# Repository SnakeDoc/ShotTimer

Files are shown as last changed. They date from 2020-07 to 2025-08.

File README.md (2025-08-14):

Shot Timer
===============================================================================

Copyright 2018 Jason Sipula

A sport shooting training aid that tracks individual shot times, splits and more.

_______________________________________________________________________________

Completed Hardware (LCD Screen disconnected for testing):
PXL_20220328_060556734-EDIT



Circuit Schematic:
schematic

Traces:


Ground and Power Planes:


Bare Board (hand for scale reference):




Board Assembly:




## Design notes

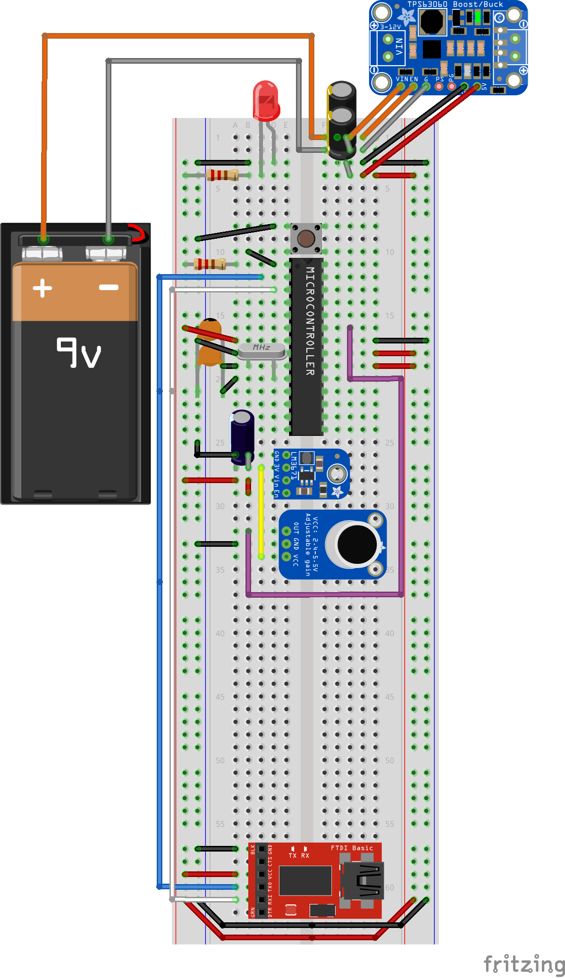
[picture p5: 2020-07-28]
ShotTimer/ShotTimer/hardware/designs/breadboard/Breadboard_Design_bb.png

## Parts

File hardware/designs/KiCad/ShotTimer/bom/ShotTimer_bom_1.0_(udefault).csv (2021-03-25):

Component | Quantity | Reference Designator | Customer Reference | Value | Quantity Per PCB | Digi-Key Part Number | Manufacturer | Manufacturer Part Number | Footprint | Description | Datasheet | Part | References | UserGuide
1 | 1 | BZ1 | BZ1 | Speaker | 1 | 445-2526-1-ND | TDK Corporation | PS1420P02CT | PS1420P02CT | Buzzer, polarized | https://product.tdk.com/info/en/catalog/datasheets/piezoelectronic_buzzer_ps_en.pdf | Buzzer | BZ1
2 | 2 | C15 C16 | C15 C16 | 22pF | 2 | BC1005CT-ND | Vishay Beyschlag/Draloric/BC Components | K220J15C0GF5TL2 | C_Disc_D3.8mm_W2.6mm_P2.50mm | Unpolarized capacitor | https://www.vishay.com/docs/45171/kseries.pdf | C | C15 C16
3 | 1 | C25 | C25 | 100pF | 1 | BC1013CT-ND | Vishay Beyschlag/Draloric/BC Components | K101J15C0GF5TL2 | C_Disc_D3.8mm_W2.6mm_P2.50mm | Unpolarized capacitor | https://www.vishay.com/docs/45171/kseries.pdf | C | C25
4 | 1 | C23 | C23 | 10nF | 1 | 445-173474-1-ND | TDK Corporation | FG28C0G1H103JNT06 | C_Disc_D4.7mm_W2.5mm_P5.00mm | Unpolarized capacitor | https://product.tdk.com/info/en/catalog/datasheets/leadmlcc_halogenfree_fg_en.pdf | C | C23
5 | 10 | C3 C4 C9 C11 C13 C14 C17 C21 C22 C26 | C3 C4 C9 C11 C13 C14 C17 C21 C22 C26 | 0.1uF | 10 | 399-13932-ND | KEMET | C322C104J5R5TA | C_Disc_D5.1mm_W3.2mm_P5.00mm | Unpolarized capacitor | https://content.kemet.com/datasheets/KEM_C1050_GOLDMAX_X7R.pdf | C | C3 C4 C9 C11 C13 C14 C17 C21 C22 C26
6 | 1 | C24 | C24 | 1uF | 1 | 399-13901-ND | KEMET | C330C105J5R5TA | C_Disc_D7.5mm_W4.4mm_P5.00mm | Unpolarized capacitor | https://product.tdk.com/info/en/catalog/datasheets/leadmlcc_halogenfree_fg_en.pdf | C | C24
7 | 9 | C1 C2 C8 C10 C12 C18 C19 C20 C27 | C1 C2 C8 C10 C12 C18 C19 C20 C27 | 10uF | 9 | 445-173370-1-ND | TDK Corporation | FG24X7R1A106KRT06 | C_Disc_D4.7mm_W2.5mm_P5.00mm | Polarized capacitor, US symbol | https://product.tdk.com/info/en/catalog/datasheets/leadmlcc_halogenfree_fg_en.pdf | CP1 | C1 C2 C8 C10 C12 C18 C19 C20 C27
8 | 3 | C5 C6 C7 | C5 C6 C7 | 220uF | 3 | P16296-ND | Panasonic Electronic Components | 16SEPC220MD | CP_Radial_D8.0mm_P3.50mm | Polarized capacitor, US symbol | https://industrial.panasonic.com/cdbs/www-data/pdf/AAB8000/AAB8000C247.pdf | CP1 | C5 C6 C7
9 | 11 | D1 D2 D3 D4 D5 D6 D7 D8 D9 D10 D11 | D1 D2 D3 D4 D5 D6 D7 D8 D9 D10 D11 | 1N5817 | 11 | 497-4547-1-ND | STMicroelectronics | 1N5817 | D_DO-41_SOD81_P10.16mm_Horizontal | 20V 1A Schottky Barrier Rectifier Diode, DO-41 | https://www.st.com/content/ccc/resource/technical/document/datasheet/26/db/14/60/52/47/47/5b/CD00001625.pdf/files/CD00001625.pdf/jcr:content/translations/en.C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 | 1N5817 | D1 D2 D3 D4 D5 D6 D7 D8 D9 D10 D11
10 | 1 | DS1 | DS1 | NHD-0420CW-SPI | 1 | NHD-0420CW-AB3-ND | Newhaven Display Intl | NHD-0420CW-AB3 | NHD_NHD-0420CW-AG3 | 20x4 Character LCD Display Module Passive 5 x 8 Dots OLED Parallel, 8-Bit, I²C, SPI | https://www.newhavendisplay.com/specs/NHD-0420CW-AB3.pdf | NHD-0420CW-SPI | DS1 | https://www.newhavendisplay.com/app_notes/US2066.pdf
11 | 2 | FB1 FB2 | FB1 FB2 | Ferrite_Bead | 2 | 240-2493-ND | Laird-Signal Integrity Products | 28C0236-0JW-10 | LairdTech_28C0236-0JW-10 | Ferrite bead | https://media.digikey.com/pdf/Data%20Sheets/Steward%20PDFs/Part%20Number%20Guide.pdf | Ferrite_Bead | FB1 FB2
12 | 1 | J4 | J4 | Conn_01x20 | 1 | S7053-ND | Sullins Connector Solutions | PPPC201LFBN-RC | PinSocket_1x20_P2.54mm_Vertical | Generic connector, single row, 01x20, script generated (kicad-library-utils/schlib/autogen/connector/) | ~ | Conn_01x20 | J4
13 | 1 | J5 | J5 | Conn_01x20 | 1 | S1211E-20-ND | Sullins Connector Solutions | PBC20SFAN | PinHeader_1x20_P2.54mm_Vertical | Generic connector, single row, 01x20, script generated (kicad-library-utils/schlib/autogen/connector/) | ~ | Conn_01x20 | J5
14 | 1 | J2 | J2 | ISP | 1 | 2057-PH2-06-UA-ND | Adam Tech | PH2-06-UA | PinHeader_2x03_P2.54mm_Vertical | Generic connector, double row, 02x03, odd/even pin numbering scheme (row 1 odd numbers, row 2 even numbers), script generated (kicad-library-utils/schlib/autogen/connector/) | ~ | Conn_02x03_Odd_Even | J2
15 | 1 | J3 | J3 | SERIAL | 1 | 2057-PH1-02-UA-ND | Adam Tech | PH1-02-UA | PinHeader_1x02_P2.54mm_Vertical | Generic connector, single row, 01x02, script generated (kicad-library-utils/schlib/autogen/connector/) | ~ | Conn_01x02 | J3
16 | 1 | J1 | J1 | SYS_PWR | 1 | 732-10955-ND | Würth Elektronik | 691137710002 | TerminalBlock_bornier-2_P5.08mm | Generic screw terminal, single row, 01x02, script generated (kicad-library-utils/schlib/autogen/connector/) | https://www.we-online.de/katalog/datasheet/691137710002.pdf | Screw_Terminal_01x02 | J1
17 | 1 | JP2 | JP2 | ISP_PWR | 1 | 2057-PH1-03-UA-ND | Adam Tech | PH1-03-UA | PinHeader_1x03_P2.54mm_Vertical | Dual jumper, normally closed | ~ | Jumper_NC_Dual | JP2
18 | 1 | JP1 | JP1 | SYS_CFG | 1 | 2057-PH1-02-UA-ND | Adam Tech | PH1-02-UA | PinHeader_1x02_P2.54mm_Vertical | Jumper, 2-pole, open | ~ | Jumper_2_Open | JP1
19 | 1 | L1 | L1 | 33uH | 1 | 308-2103-ND | Sumida America Components Inc. | RCH895NP-330K | L_Radial_D7.8mm_P5.00mm_Fastron_07HCP | Inductor | http://products.sumida.com/products/pdf/RCH-895.pdf | L | L1
20 | 1 | LED1 | LED1 | Green | 1 | 732-5007-ND | Würth Elektronik | 151031VS04000 | LED_D3.0mm | Light emitting diode | https://www.we-online.de/katalog/datasheet/151031VS04000.pdf | LED | LED1
21 | 1 | LED3 | LED3 | Red | 1 | 732-5005-ND | Würth Elektronik | 151031SS04000 | LED_D3.0mm | Light emitting diode | https://katalog.we-online.de/led/datasheet/151031SS04000.pdf | LED | LED3
22 | 2 | LED2 LED4 | LED2 LED4 | Yellow | 2 | 732-5010-ND | Würth Elektronik | 151031YS06000 | LED_D3.0mm | Light emitting diode | https://www.we-online.de/katalog/datasheet/151031YS06000.pdf | LED | LED2 LED4
23 | 1 | MK1 | MK1 | CMA-4544PF-W | 1 | 102-1721-ND | CUI Devices | CMA-4544PF-W | MIC_CMA-4544PF-W |  | https://www.cuidevices.com/product/resource/cma-4544pf-w.pdf | CMA-4544PF-W | MK1
24 | 1 | Q1 | Q1 | Q_NPN_EBC | 1 | KSP2222ABUFS-ND | ON Semiconductor | KSP2222ABU | TO-92 | NPN transistor, emitter/base/collector | https://www.onsemi.com/pub/Collateral/KSP2222A-D.PDF | Q_NPN_EBC | Q1
25 | 1 | Q2 | Q2 | Q_PNP_CBE | 1 | PN2907-ND | ON Semiconductor | PN2907BU | TO-92 | PNP transistor, collector/base/emitter | https://media.digikey.com/pdf/Data%20Sheets/Fairchild%20PDFs/MMBT2907A_PN2907A_PZT2907A.pdf | Q_PNP_CBE | Q2
26 | 4 | R21 R22 R23 R24 | R21 R22 R23 R24 | 330 | 4 | S330CACT-ND | Stackpole Electronics Inc | RNMF14FTC330R | R_Axial_DIN0204_L3.6mm_D1.6mm_P5.08mm_Horizontal | Resistor, US symbol | https://www.seielect.com/catalog/sei-rnf_rnmf.pdf | R_US | R21 R22 R23 R24
27 | 1 | R17 | R17 | 1K | 1 | RNF14FTD1K00CT-ND | Stackpole Electronics Inc | RNF14FTD1K00 | R_Axial_DIN0207_L6.3mm_D2.5mm_P7.62mm_Horizontal | Resistor, US symbol | https://www.seielect.com/catalog/sei-rnf_rnmf.pdf | R_US | R17
28 | 2 | R29 R30 | R29 R30 | 2K | 2 | RNF14FTD2K00CT-ND | Stackpole Electronics Inc | RNF14FTD2K00 | R_Axial_DIN0207_L6.3mm_D2.5mm_P7.62mm_Horizontal | Resistor, US symbol | https://www.seielect.com/catalog/sei-rnf_rnmf.pdf | R_US | R29 R30
29 | 25 | R1 R2 R3 R6 R7 R8 R9 R10 R11 R12 R13 R14 R16 R18 R19 R20 R25 R26 R27 R28 R31 R32 R35 R36 R37 | R1 R2 R3 R6 R7 R8 R9 R10 R11 R12 R13 R14 R16 R18 R19 R20 R25 R26 R27 R28 R31 R32 R35 R36 R37 | 10K | 25 | RNF14FTD10K0CT-ND | Stackpole Electronics Inc | RNF14FTD10K0 | R_Axial_DIN0207_L6.3mm_D2.5mm_P7.62mm_Horizontal | Resistor, US symbol | https://www.seielect.com/catalog/sei-rnf_rnmf.pdf | R_US | R1 R2 R3 R6 R7 R8 R9 R10 R11 R12 R13 R14 R16 R18 R19 R20 R25 R26 R27 R28 R31 R32 R35 R36 R37
30 | 2 | R15 R38 | R15 R38 | 100K | 2 | RNF14FTD100KCT-ND | Stackpole Electronics Inc | RNF14FTD100K | R_Axial_DIN0207_L6.3mm_D2.5mm_P7.62mm_Horizontal | Resistor, US symbol | https://www.seielect.com/catalog/sei-rnf_rnmf.pdf | R_US | R15 R38
31 | 2 | R33 R34 | R33 R34 | 1M | 2 | RNF14FTD1M00CT-ND | Stackpole Electronics Inc | RNF14FTD1M00 | R_Axial_DIN0207_L6.3mm_D2.5mm_P7.62mm_Horizontal | Resistor, US symbol | https://www.seielect.com/catalog/sei-rnf_rnmf.pdf | R_US | R33 R34
32 | 1 | R4 | R4 | 316K 1% | 1 | RNF14FTD316KCT-ND | Stackpole Electronics Inc | RNF14FTD316K | R_Axial_DIN0207_L6.3mm_D2.5mm_P7.62mm_Horizontal | Resistor, US symbol | https://www.seielect.com/catalog/sei-rnf_rnmf.pdf | R_US | R4
33 | 1 | R5 | R5 | 412K 1% | 1 | RNF14FTD412KCT-ND | Stackpole Electronics Inc | RNF14FTD412K | R_Axial_DIN0207_L6.3mm_D2.5mm_P7.62mm_Horizontal | Resistor, US symbol | https://www.seielect.com/catalog/sei-rnf_rnmf.pdf | R_US | R5
34 | 8 | SW1 SW2 SW3 SW4 SW5 SW6 SW7 SW8 | SW1 SW2 SW3 SW4 SW5 SW6 SW7 SW8 | BTN | 8 | SW400-ND | Omron Electronics Inc-EMC Div | B3F-1000 | SW_TH_Tactile_Omron_B3F-10xx | Push button switch, generic, two pins | https://omronfs.omron.com/en_US/ecb/products/pdf/en-b3f.pdf | SW_Push | SW1 SW2 SW3 SW4 SW5 SW6 SW7 SW8
35 | 1 | SW9 | SW9 | Reset | 1 | SW950-ND | Omron Electronics Inc-EMC Div | B3F-1006 | SW_TH_Tactile_Omron_B3F-10xx | Push button switch, generic, two pins | https://omronfs.omron.com/en_US/ecb/products/pdf/en-b3f.pdf | SW_Push | SW9
36 | 1 | U7 | U7 | 25LC1024-I/P | 1 | 25LC1024-I/P-ND | Microchip Technology | 25LC1024-I/P | DIP-8_W7.62mm | SPI Serial EEPROM, DIP-8/SOIC-8/TSSOP-8 | https://ww1.microchip.com/downloads/en/DeviceDoc/22064D.pdf | 25LCxxx | U7
37 | 1 | U5 | U5 | ATmega328P-PU | 1 | ATMEGA328P-PU-ND | Microchip Technology | ATMEGA328P-PU | DIP-28_W7.62mm |  | http://ww1.microchip.com/downloads/en/DeviceDoc/ATmega328_P%20AVR%20MCU%20with%20picoPower%20Technology%20Data%20Sheet%2040001984A.pdf | ATmega328P-PU-UserLibrary | U5
38 | 1 | U4 | U4 | LT1303CN8-5#PBF | 1 | LT1303CN8-5#PBF-ND | Analog Devices Inc. | LT1303CN8-5#PBF | PDIP-8_N |  | https://www.analog.com/media/en/technical-documentation/data-sheets/lt1303.pdf | LT1303CN8-5#PBF-UserLibrary | U4
39 | 1 | U8 | U8 | MAX4466EXK | 1 | MAX4466EXK+CT-ND | Maxim Integrated | MAX4466EXK+T | SOT65P210X110-5N |  | https://datasheets.maximintegrated.com/en/ds/MAX4465-MAX4469.pdf | MAX4466EXK | U8
40 | 1 | U6 | U6 | MCP3201 | 1 | MCP3201-CI/P-ND | Microchip Technology | MCP3201-CI/P | DIP-8_W7.62mm |  | https://ww1.microchip.com/downloads/en/DeviceDoc/21290F.pdf | MCP3201_TriStateMISO-UserLibrary | U6
41 | 1 | U3 | U3 | RN4871-I/RM140 | 1 | 150-RN4871-I/RM140-ND | Microchip Technology | RN4871-I/RM140 | Microchip_RN4871 | Bluetooth Low Energy 4.2 Module | https://ww1.microchip.com/downloads/en/DeviceDoc/RN4870-71-Data-Sheet-DS50002489E.pdf | RN4871 | U3 | https://ww1.microchip.com/downloads/en/DeviceDoc/RN4870-71-Bluetooth-Low-Energy-Module-User-Guide-DS50002466C.pdf
42 | 1 | U1 | U1 | SN74HC153N | 1 | 296-8238-5-ND | Texas Instruments | SN74HC153N | DIP794W45P254L1969H508Q16 |  | https://www.ti.com/lit/ds/symlink/sn74hc153.pdf | SN74HC153N | U1
43 | 1 | U2 | U2 | TSR_1-2433 | 1 | 1951-2742-ND | Traco Power | TSR 1-2433 | Converter_DCDC_TRACO_TSR-1_THT | 1A step-down regulator module, fixed 3.3V output voltage, 5-36V input voltage, -40°C to +85°C temperature range, TO-220 compatible LM78xx replacement | https://www.tracopower.com/sites/default/files/products/datasheets/tsr1_datasheet.pdf | TSR_1-2433 | U2
44 | 1 | Y1 | Y1 | 16MHz | 1 | 887-1244-ND | TXC CORPORATION | 9B-16.000MEEJ-B | Crystal_HC49-U_Vertical | Two pin crystal | http://www.txccrystal.com/images/pdf/9b-accuracy.pdf | Crystal | Y1
Component Groups: | 44
Component Count: | 113
Fitted Components: | 113
Number of PCBs: | 1
Total components: | 113
Schematic Version: | 1.0
Schematic Date: | 2021-02-14
PCB Variant: | udefault
BoM Date: | 2/17/2021 12:20:09 AM
Schematic Source: | ShotTimer.sch
KiCad Version: | Eeschema (5.1.9)-1

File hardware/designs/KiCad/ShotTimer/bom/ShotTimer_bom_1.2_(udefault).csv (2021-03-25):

Component | Quantity | Reference Designator | Customer Reference | Value | Quantity Per PCB | Digi-Key Part Number | Manufacturer | Manufacturer Part Number | Footprint | Description | Datasheet | Part | Mouser Part Number | Build Quantity | References | UserGuide
1 | 3 | BZ1 | BZ1 | Speaker | 1 | 445-2526-1-ND | TDK Corporation | PS1420P02CT | PS1420P02CT | Buzzer, polarized | https://product.tdk.com/info/en/catalog/datasheets/piezoelectronic_buzzer_ps_en.pdf | Buzzer | 810-PS1420P02CT | 3 | BZ1
2 | 6 | C15 C16 | C15 C16 | 22pF | 2 | BC1005CT-ND | Vishay Beyschlag/Draloric/BC Components | K220J15C0GF5TL2 | C_Disc_D3.8mm_W2.6mm_P2.50mm | Unpolarized capacitor | https://www.vishay.com/docs/45171/kseries.pdf | C | 594-K220J15C0GF5TL2 | 6 | C15 C16
3 | 3 | C25 | C25 | 100pF | 1 | BC1013CT-ND | Vishay Beyschlag/Draloric/BC Components | K101J15C0GF5TL2 | C_Disc_D3.8mm_W2.6mm_P2.50mm | Unpolarized capacitor | https://www.vishay.com/docs/45171/kseries.pdf | C | 594-K101J15C0GF5TL2 | 3 | C25
4 | 3 | C23 | C23 | 10nF | 1 | 445-173474-1-ND | TDK Corporation | FG28C0G1H103JNT06 | C_Disc_D4.7mm_W2.5mm_P5.00mm | Unpolarized capacitor | https://product.tdk.com/info/en/catalog/datasheets/leadmlcc_halogenfree_fg_en.pdf | C | 810-FG28C0G1H103JNT6 | 3 | C23
5 | 33 | C1 C2 C3 C4 C9 C13 C14 C17 C21 C22 C26 | C1 C2 C3 C4 C9 C13 C14 C17 C21 C22 C26 | 0.1uF | 11 | 399-13932-ND | KEMET | C322C104J5R5TA | C_Disc_D5.1mm_W3.2mm_P5.00mm | Unpolarized capacitor | https://content.kemet.com/datasheets/KEM_C1050_GOLDMAX_X7R.pdf | C | 80-C322C104J5R | 33 | C1 C2 C3 C4 C9 C13 C14 C17 C21 C22 C26
6 | 3 | C24 | C24 | 1uF | 1 | 399-13901-ND | KEMET | C330C105J5R5TA | C_Disc_D7.5mm_W4.4mm_P5.00mm | Unpolarized capacitor | https://product.tdk.com/info/en/catalog/datasheets/leadmlcc_halogenfree_fg_en.pdf | C | 80-C330C105J5R | 3 | C24
7 | 9 | C5 C6 C7 | C5 C6 C7 | 220uF | 3 | P16296-ND | Panasonic Electronic Components | 16SEPC220MD | CP_Radial_D8.0mm_P3.50mm | Polarized capacitor, US symbol | https://industrial.panasonic.com/cdbs/www-data/pdf/AAB8000/AAB8000C247.pdf | CP1 | 667-16SEPC220MD | 9 | C5 C6 C7
8 | 33 | D1 D2 D3 D4 D5 D6 D7 D8 D9 D10 D11 | D1 D2 D3 D4 D5 D6 D7 D8 D9 D10 D11 | 1N5817 | 11 | 497-4547-1-ND | STMicroelectronics | 1N5817 | D_DO-41_SOD81_P10.16mm_Horizontal | 20V 1A Schottky Barrier Rectifier Diode, DO-41 | https://www.st.com/content/ccc/resource/technical/document/datasheet/26/db/14/60/52/47/47/5b/CD00001625.pdf/files/CD00001625.pdf/jcr:content/translations/en.C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 | 1N5817 | 511-1N5817 | 33 | D1 D2 D3 D4 D5 D6 D7 D8 D9 D10 D11
9 | 3 | DS1 | DS1 | NHD-0420CW-SPI | 1 | NHD-0420CW-AB3-ND | Newhaven Display Intl | NHD-0420CW-AB3 | NHD_NHD-0420CW-AG3 | 20x4 Character LCD Display Module Passive 5 x 8 Dots OLED Parallel, 8-Bit, I²C, SPI | https://www.newhavendisplay.com/specs/NHD-0420CW-AB3.pdf | NHD-0420CW-SPI | 763-NHD-0420CW-AB3 | 3 | DS1 | https://www.newhavendisplay.com/app_notes/US2066.pdf
10 | 6 | FB1 FB2 | FB1 FB2 | Ferrite_Bead | 2 | 240-2493-ND | Laird-Signal Integrity Products | 28C0236-0JW-10 | LairdTech_28C0236-0JW-10 | Ferrite bead | https://media.digikey.com/pdf/Data%20Sheets/Steward%20PDFs/Part%20Number%20Guide.pdf | Ferrite_Bead | 875-28C0236-0JW-10 | 6 | FB1 FB2
11 | 3 | J2 | J2 | ISP | 1 | 2057-PH2-06-UA-ND | Adam Tech | PH2-06-UA | PinHeader_2x03_P2.54mm_Vertical | Generic connector, double row, 02x03, odd/even pin numbering scheme (row 1 odd numbers, row 2 even numbers), script generated (kicad-library-utils/schlib/autogen/connector/) | ~ | Conn_02x03_Odd_Even |  | 3 | J2
12 | 3 | J3 | J3 | SERIAL | 1 | 2057-PH1-02-UA-ND | Adam Tech | PH1-02-UA | PinHeader_1x02_P2.54mm_Vertical | Generic connector, single row, 01x02, script generated (kicad-library-utils/schlib/autogen/connector/) | ~ | Conn_01x02 |  | 3 | J3
13 | 3 | J1 | J1 | SYS_PWR | 1 | 732-10955-ND | Würth Elektronik | 691137710002 | TerminalBlock_bornier-2_P5.08mm | Generic screw terminal, single row, 01x02, script generated (kicad-library-utils/schlib/autogen/connector/) | https://www.we-online.de/katalog/datasheet/691137710002.pdf | Screw_Terminal_01x02 | 710-691137710002 | 3 | J1
14 | 3 | JP2 | JP2 | ISP_PWR | 1 | 2057-PH1-03-UA-ND | Adam Tech | PH1-03-UA | PinHeader_1x03_P2.54mm_Vertical | Dual jumper, normally closed | ~ | Jumper_NC_Dual |  | 3 | JP2
15 | 3 | JP1 | JP1 | SYS_CFG | 1 | 2057-PH1-02-UA-ND | Adam Tech | PH1-02-UA | PinHeader_1x02_P2.54mm_Vertical | Jumper, 2-pole, open | ~ | Jumper_2_Open |  | 3 | JP1
16 | 3 | L1 | L1 | 33uH | 1 | 308-2103-ND | Sumida America Components Inc. | RCH895NP-330K | L_Radial_D7.8mm_P5.00mm_Fastron_07HCP | Inductor | http://products.sumida.com/products/pdf/RCH-895.pdf | L | 851-RCH895NP-330K | 3 | L1
17 | 3 | LED1 | LED1 | Green | 1 | 732-5007-ND | Würth Elektronik | 151031VS04000 | LED_D3.0mm | Light emitting diode | https://www.we-online.de/katalog/datasheet/151031VS04000.pdf | LED | 710-151031VS04000 | 3 | LED1
18 | 3 | LED3 | LED3 | Red | 1 | 732-5005-ND | Würth Elektronik | 151031SS04000 | LED_D3.0mm | Light emitting diode | https://katalog.we-online.de/led/datasheet/151031SS04000.pdf | LED | 710-151031SS04000 | 3 | LED3
19 | 6 | LED2 LED4 | LED2 LED4 | Yellow | 2 | 732-5010-ND | Würth Elektronik | 151031YS06000 | LED_D3.0mm | Light emitting diode | https://www.we-online.de/katalog/datasheet/151031YS06000.pdf | LED | 710-151031YS06000 | 6 | LED2 LED4
20 | 3 | MK1 | MK1 | CMA-4544PF-W | 1 | 102-1721-ND | CUI Devices | CMA-4544PF-W | MIC_CMA-4544PF-W |  | https://www.cuidevices.com/product/resource/cma-4544pf-w.pdf | CMA-4544PF-W | 490-CMA-4544PF-W | 3 | MK1
21 | 3 | Q1 | Q1 | Q_NPN_EBC | 1 | KSP2222ABUFS-ND | ON Semiconductor | KSP2222ABU | TO-92 | NPN transistor, emitter/base/collector | https://www.onsemi.com/pub/Collateral/KSP2222A-D.PDF | Q_NPN_EBC | 512-KSP2222ABU | 3 | Q1
22 | 3 | Q2 | Q2 | Q_PNP_CBE | 1 | PN2907-ND | ON Semiconductor | PN2907BU | TO-92 | PNP transistor, collector/base/emitter | https://media.digikey.com/pdf/Data%20Sheets/Fairchild%20PDFs/MMBT2907A_PN2907A_PZT2907A.pdf | Q_PNP_CBE | 512-PN2907BU | 3 | Q2
23 | 12 | R21 R22 R23 R24 | R21 R22 R23 R24 | 330 | 4 | S330CACT-ND | Stackpole Electronics Inc | RNMF14FTC330R | R_Axial_DIN0204_L3.6mm_D1.6mm_P5.08mm_Horizontal | Resistor, US symbol | https://www.seielect.com/catalog/sei-rnf_rnmf.pdf | R_US |  | 12 | R21 R22 R23 R24
24 | 3 | R17 | R17 | 1K | 1 | RNF14FTD1K00CT-ND | Stackpole Electronics Inc | RNF14FTD1K00 | R_Axial_DIN0207_L6.3mm_D2.5mm_P7.62mm_Horizontal | Resistor, US symbol | https://www.seielect.com/catalog/sei-rnf_rnmf.pdf | R_US |  | 3 | R17
25 | 6 | R29 R30 | R29 R30 | 2K | 2 | RNF14FTD2K00CT-ND | Stackpole Electronics Inc | RNF14FTD2K00 | R_Axial_DIN0207_L6.3mm_D2.5mm_P7.62mm_Horizontal | Resistor, US symbol | https://www.seielect.com/catalog/sei-rnf_rnmf.pdf | R_US |  | 6 | R29 R30
26 | 78 | R1 R2 R3 R6 R7 R8 R9 R10 R11 R12 R13 R14 R16 R18 R19 R20 R25 R26 R27 R28 R31 R32 R35 R36 R37 R39 | R1 R2 R3 R6 R7 R8 R9 R10 R11 R12 R13 R14 R16 R18 R19 R20 R25 R26 R27 R28 R31 R32 R35 R36 R37 R39 | 10K | 26 | RNF14FTD10K0CT-ND | Stackpole Electronics Inc | RNF14FTD10K0 | R_Axial_DIN0207_L6.3mm_D2.5mm_P7.62mm_Horizontal | Resistor, US symbol | https://www.seielect.com/catalog/sei-rnf_rnmf.pdf | R_US |  | 78 | R1 R2 R3 R6 R7 R8 R9 R10 R11 R12 R13 R14 R16 R18 R19 R20 R25 R26 R27 R28 R31 R32 R35 R36 R37 R39
27 | 6 | R15 R38 | R15 R38 | 100K | 2 | RNF14FTD100KCT-ND | Stackpole Electronics Inc | RNF14FTD100K | R_Axial_DIN0207_L6.3mm_D2.5mm_P7.62mm_Horizontal | Resistor, US symbol | https://www.seielect.com/catalog/sei-rnf_rnmf.pdf | R_US |  | 6 | R15 R38
28 | 6 | R33 R34 | R33 R34 | 1M | 2 | RNF14FTD1M00CT-ND | Stackpole Electronics Inc | RNF14FTD1M00 | R_Axial_DIN0207_L6.3mm_D2.5mm_P7.62mm_Horizontal | Resistor, US symbol | https://www.seielect.com/catalog/sei-rnf_rnmf.pdf | R_US |  | 6 | R33 R34
29 | 3 | R4 | R4 | 316K 1% | 1 | RNF14FTD316KCT-ND | Stackpole Electronics Inc | RNF14FTD316K | R_Axial_DIN0207_L6.3mm_D2.5mm_P7.62mm_Horizontal | Resistor, US symbol | https://www.seielect.com/catalog/sei-rnf_rnmf.pdf | R_US |  | 3 | R4
30 | 3 | R5 | R5 | 412K 1% | 1 | RNF14FTD412KCT-ND | Stackpole Electronics Inc | RNF14FTD412K | R_Axial_DIN0207_L6.3mm_D2.5mm_P7.62mm_Horizontal | Resistor, US symbol | https://www.seielect.com/catalog/sei-rnf_rnmf.pdf | R_US |  | 3 | R5
31 | 24 | SW1 SW2 SW3 SW4 SW5 SW6 SW7 SW8 | SW1 SW2 SW3 SW4 SW5 SW6 SW7 SW8 | BTN | 8 | SW400-ND | Omron Electronics Inc-EMC Div | B3F-1000 | SW_B3F-10xx | Push button switch, generic, two pins | https://omronfs.omron.com/en_US/ecb/products/pdf/en-b3f.pdf | SW_Push_2-4 | 653-B3F-1000 | 24 | SW1 SW2 SW3 SW4 SW5 SW6 SW7 SW8
32 | 3 | SW9 | SW9 | Reset | 1 | SW950-ND | Omron Electronics Inc-EMC Div | B3F-1006 | SW_B3F-10xx | Push button switch, generic, two pins | https://omronfs.omron.com/en_US/ecb/products/pdf/en-b3f.pdf | SW_Push_1-3 | 653-B3F-1006 | 3 | SW9
33 | 3 | U7 | U7 | 25LC1024-I/P | 1 | 25LC1024-I/P-ND | Microchip Technology | 25LC1024-I/P | DIP-8_W7.62mm | SPI Serial EEPROM, DIP-8/SOIC-8/TSSOP-8 | https://ww1.microchip.com/downloads/en/DeviceDoc/22064D.pdf | 25LCxxx | 579-25LC1024-I/P | 3 | U7
34 | 3 | U5 | U5 | ATmega328P-PU | 1 | ATMEGA328P-PU-ND | Microchip Technology | ATMEGA328P-PU | DIP-28_W7.62mm |  | http://ww1.microchip.com/downloads/en/DeviceDoc/ATmega328_P%20AVR%20MCU%20with%20picoPower%20Technology%20Data%20Sheet%2040001984A.pdf | ATmega328P-PU-UserLibrary | 556-ATMEGA328P-PU | 3 | U5
35 | 3 | U1 | U1 | CD74HC151E | 1 | 296-25973-5-ND | Texas Instruments | CD74HC151E | DIP-16_W7.62mm |  | https://www.ti.com/lit/ds/symlink/cd74hc151.pdf | CD74HC151E-EZLayout | 595-CD74HC151E | 3 | U1
36 | 3 | U4 | U4 | LT1303CN8-5#PBF | 1 | LT1303CN8-5#PBF-ND | Analog Devices Inc. | LT1303CN8-5#PBF | PDIP-8_N |  | https://www.analog.com/media/en/technical-documentation/data-sheets/lt1303.pdf | LT1303CN8-5#PBF-UserLibrary | 584-LT1303CN8-5#PBF | 3 | U4
37 | 3 | U8 | U8 | MAX4466EXK | 1 | MAX4466EXK+CT-ND | Maxim Integrated | MAX4466EXK+T | SOT65P210X110-5N |  | https://datasheets.maximintegrated.com/en/ds/MAX4465-MAX4469.pdf | MAX4466EXK | 700-MAX4466EXKT | 3 | U8
38 | 3 | U6 | U6 | MCP3201 | 1 | MCP3201-CI/P-ND | Microchip Technology | MCP3201-CI/P | DIP-8_W7.62mm |  | https://ww1.microchip.com/downloads/en/DeviceDoc/21290F.pdf | MCP3201_TriStateMISO-UserLibrary | 579-MCP3201-CI/P | 3 | U6
39 | 3 | U3 | U3 | RN4871-I/RM140 | 1 | 150-RN4871-I/RM140-ND | Microchip Technology | RN4871-I/RM140 | Microchip_RN4871 | Bluetooth Low Energy 4.2 Module | https://ww1.microchip.com/downloads/en/DeviceDoc/RN4870-71-Data-Sheet-DS50002489E.pdf | RN4871 | 579-RN4871-I/RM140 | 3 | U3 | https://ww1.microchip.com/downloads/en/DeviceDoc/RN4870-71-Bluetooth-Low-Energy-Module-User-Guide-DS50002466C.pdf
40 | 3 | U2 | U2 | TSR_1-2433 | 1 | 1951-2742-ND | Traco Power | TSR 1-2433 | Converter_DCDC_TRACO_TSR-1_THT | 1A step-down regulator module, fixed 3.3V output voltage, 5-36V input voltage, -40°C to +85°C temperature range, TO-220 compatible LM78xx replacement | https://www.tracopower.com/sites/default/files/products/datasheets/tsr1_datasheet.pdf | TSR_1-2433 | 495-TSR-1-2433 | 3 | U2
41 | 3 | Y1 | Y1 | 16MHz | 1 | 887-1244-ND | TXC CORPORATION | 9B-16.000MEEJ-B | Crystal_HC49-U_Vertical | Two pin crystal | http://www.txccrystal.com/images/pdf/9b-accuracy.pdf | Crystal | 717-9B-16.000MEEJ-B | 3 | Y1
Component Groups: | 41
Component Count: | 104
Fitted Components: | 104
Number of PCBs: | 3
Total components: | 312
Schematic Version: | 1.2
Schematic Date: | 2021-03-06
PCB Variant: | udefault
BoM Date: | 3/8/2021 11:59:04 PM
Schematic Source: | ShotTimer.sch
KiCad Version: | Eeschema (5.1.9)-1

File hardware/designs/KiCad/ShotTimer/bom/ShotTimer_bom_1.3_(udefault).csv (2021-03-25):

Component | Quantity | Reference Designator | Customer Reference | Value | Quantity Per PCB | Digi-Key Part Number | Manufacturer | Manufacturer Part Number | Footprint | Description | Datasheet | Part | Build Quantity | References | Mouser Part Number | UserGuide
1 | 4 | BOM1 BOM2 | BOM1 BOM2 | Jumper | 2 | S9337-ND | Sullins Connector Solutions | QPC02SXGN-RC |  |  | https://s3.amazonaws.com/catalogspreads-pdf/PAGE128-129%20.100%20JUMPER.pdf | BOM_ITEM-UserLibrary | 4 | BOM1 BOM2
2 | 4 | BOM3 BOM4 | BOM3 BOM4 | Support | 2 | RPC1348-ND | Essentra Components | MDLSP1-09M-01 |  |  | https://www.essentracomponents.com.sg/images-line/pdfs/MDLSP1-09M-01.pdf | BOM_ITEM-UserLibrary | 4 | BOM3 BOM4
3 | 2 | BZ1 | BZ1 | Speaker | 1 | 445-2526-1-ND | TDK Corporation | PS1420P02CT | PS1420P02CT | Buzzer, polarized | https://product.tdk.com/info/en/catalog/datasheets/piezoelectronic_buzzer_ps_en.pdf | Buzzer | 2 | BZ1 | 810-PS1420P02CT
4 | 4 | C15 C16 | C15 C16 | 22pF | 2 | BC1005CT-ND | Vishay Beyschlag/Draloric/BC Components | K220J15C0GF5TL2 | C_Disc_D3.8mm_W2.6mm_P2.50mm | Unpolarized capacitor | https://www.vishay.com/docs/45171/kseries.pdf | C | 4 | C15 C16 | 594-K220J15C0GF5TL2
5 | 2 | C25 | C25 | 100pF | 1 | BC1013CT-ND | Vishay Beyschlag/Draloric/BC Components | K101J15C0GF5TL2 | C_Disc_D3.8mm_W2.6mm_P2.50mm | Unpolarized capacitor | https://www.vishay.com/docs/45171/kseries.pdf | C | 2 | C25 | 594-K101J15C0GF5TL2
6 | 2 | C23 | C23 | 10nF | 1 | 445-173474-1-ND | TDK Corporation | FG28C0G1H103JNT06 | C_Disc_D4.7mm_W2.5mm_P5.00mm | Unpolarized capacitor | https://product.tdk.com/info/en/catalog/datasheets/leadmlcc_halogenfree_fg_en.pdf | C | 2 | C23 | 810-FG28C0G1H103JNT6
7 | 22 | C1 C2 C3 C4 C9 C13 C14 C17 C21 C22 C26 | C1 C2 C3 C4 C9 C13 C14 C17 C21 C22 C26 | 0.1uF | 11 | 399-13932-ND | KEMET | C322C104J5R5TA | C_Disc_D5.1mm_W3.2mm_P5.00mm | Unpolarized capacitor | https://content.kemet.com/datasheets/KEM_C1050_GOLDMAX_X7R.pdf | C | 22 | C1 C2 C3 C4 C9 C13 C14 C17 C21 C22 C26 | 80-C322C104J5R
8 | 2 | C24 | C24 | 1uF | 1 | 399-13901-ND | KEMET | C330C105J5R5TA | C_Disc_D7.5mm_W4.4mm_P5.00mm | Unpolarized capacitor | https://product.tdk.com/info/en/catalog/datasheets/leadmlcc_halogenfree_fg_en.pdf | C | 2 | C24 | 80-C330C105J5R
9 | 6 | C5 C6 C7 | C5 C6 C7 | 220uF | 3 | P16296-ND | Panasonic Electronic Components | 16SEPC220MD | CP_Radial_D8.0mm_P3.50mm | Polarized capacitor, US symbol | https://industrial.panasonic.com/cdbs/www-data/pdf/AAB8000/AAB8000C247.pdf | CP1 | 6 | C5 C6 C7 | 667-16SEPC220MD
10 | 22 | D1 D2 D3 D4 D5 D6 D7 D8 D9 D10 D11 | D1 D2 D3 D4 D5 D6 D7 D8 D9 D10 D11 | 1N5817 | 11 | 497-4547-1-ND | STMicroelectronics | 1N5817 | D_DO-41_SOD81_P10.16mm_Horizontal | 20V 1A Schottky Barrier Rectifier Diode, DO-41 | https://www.st.com/content/ccc/resource/technical/document/datasheet/26/db/14/60/52/47/47/5b/CD00001625.pdf/files/CD00001625.pdf/jcr:content/translations/en.C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 | 1N5817 | 22 | D1 D2 D3 D4 D5 D6 D7 D8 D9 D10 D11 | 511-1N5817
11 | 2 | DS1 | DS1 | NHD-0420CW-SPI | 1 | NHD-0420CW-AB3-ND | Newhaven Display Intl | NHD-0420CW-AB3 | NHD_NHD-0420CW-AG3 | 20x4 Character LCD Display Module Passive 5 x 8 Dots OLED Parallel, 8-Bit, I²C, SPI | https://www.newhavendisplay.com/specs/NHD-0420CW-AB3.pdf | NHD-0420CW-SPI | 2 | DS1 | 763-NHD-0420CW-AB3 | https://www.newhavendisplay.com/app_notes/US2066.pdf
12 | 4 | FB1 FB2 | FB1 FB2 | Ferrite_Bead | 2 | 240-2493-ND | Laird-Signal Integrity Products | 28C0236-0JW-10 | LairdTech_28C0236-0JW-10 | Ferrite bead | https://media.digikey.com/pdf/Data%20Sheets/Steward%20PDFs/Part%20Number%20Guide.pdf | Ferrite_Bead | 4 | FB1 FB2 | 875-28C0236-0JW-10
13 | 2 | J5 | J5 | Header Conn_01x20 | 1 | S1211E-20-ND | Sullins Connector Solutions | PBC20SFAN | PinHeader_1x20_P2.54mm_Vertical |  | ~ | BOM_ITEM-UserLibrary | 2 | J5
14 | 2 | J2 | J2 | ISP | 1 | 2057-PH2-06-UA-ND | Adam Tech | PH2-06-UA | PinHeader_2x03_P2.54mm_Vertical | Generic connector, double row, 02x03, odd/even pin numbering scheme (row 1 odd numbers, row 2 even numbers), script generated (kicad-library-utils/schlib/autogen/connector/) | ~ | Conn_02x03_Odd_Even | 2 | J2
15 | 2 | J3 | J3 | SERIAL | 1 | 2057-PH1-02-UA-ND | Adam Tech | PH1-02-UA | PinHeader_1x02_P2.54mm_Vertical | Generic connector, single row, 01x02, script generated (kicad-library-utils/schlib/autogen/connector/) | ~ | Conn_01x02 | 2 | J3
16 | 2 | J1 | J1 | SYS_PWR | 1 | 732-10955-ND | Würth Elektronik | 691137710002 | TerminalBlock_bornier-2_P5.08mm | Generic screw terminal, single row, 01x02, script generated (kicad-library-utils/schlib/autogen/connector/) | https://www.we-online.de/katalog/datasheet/691137710002.pdf | Screw_Terminal_01x02 | 2 | J1 | 710-691137710002
17 | 2 | J4 | J4 | Socket Conn_01x20 | 1 | S7053-ND | Sullins Connector Solutions | PPPC201LFBN-RC | PinSocket_1x20_P2.54mm_Vertical |  | ~ | BOM_ITEM-UserLibrary | 2 | J4
18 | 2 | JP2 | JP2 | ISP_PWR | 1 | 2057-PH1-03-UA-ND | Adam Tech | PH1-03-UA | PinHeader_1x03_P2.54mm_Vertical | Dual jumper, normally closed | ~ | Jumper_NC_Dual | 2 | JP2
19 | 2 | JP1 | JP1 | SYS_CFG | 1 | 2057-PH1-02-UA-ND | Adam Tech | PH1-02-UA | PinHeader_1x02_P2.54mm_Vertical | Jumper, 2-pole, open | ~ | Jumper_2_Open | 2 | JP1
20 | 2 | L1 | L1 | 33uH | 1 | 308-2103-ND | Sumida America Components Inc. | RCH895NP-330K | L_Radial_D7.8mm_P5.00mm_Fastron_07HCP | Inductor | http://products.sumida.com/products/pdf/RCH-895.pdf | L | 2 | L1 | 851-RCH895NP-330K
21 | 2 | LED1 | LED1 | Green | 1 | 732-5007-ND | Würth Elektronik | 151031VS04000 | LED_D3.0mm | Light emitting diode | https://www.we-online.de/katalog/datasheet/151031VS04000.pdf | LED | 2 | LED1 | 710-151031VS04000
22 | 2 | LED3 | LED3 | Red | 1 | 732-5005-ND | Würth Elektronik | 151031SS04000 | LED_D3.0mm | Light emitting diode | https://katalog.we-online.de/led/datasheet/151031SS04000.pdf | LED | 2 | LED3 | 710-151031SS04000
23 | 4 | LED2 LED4 | LED2 LED4 | Yellow | 2 | 732-5010-ND | Würth Elektronik | 151031YS06000 | LED_D3.0mm | Light emitting diode | https://www.we-online.de/katalog/datasheet/151031YS06000.pdf | LED | 4 | LED2 LED4 | 710-151031YS06000
24 | 2 | MK1 | MK1 | CMA-4544PF-W | 1 | 102-1721-ND | CUI Devices | CMA-4544PF-W | MIC_CMA-4544PF-W |  | https://www.cuidevices.com/product/resource/cma-4544pf-w.pdf | CMA-4544PF-W | 2 | MK1 | 490-CMA-4544PF-W
25 | 2 | Q1 | Q1 | Q_NPN_EBC | 1 | SS8050DBU-ND | ON Semiconductor | SS8050DBU | TO-92 | NPN transistor, emitter/base/collector | https://www.onsemi.com/pdf/datasheet/ss8050-d.pdf | Q_NPN_EBC | 2 | Q1 | 512-SS8050DBU
26 | 2 | Q2 | Q2 | Q_PNP_CBE | 1 | PN2907-ND | ON Semiconductor | PN2907BU | TO-92 | PNP transistor, collector/base/emitter | https://media.digikey.com/pdf/Data%20Sheets/Fairchild%20PDFs/MMBT2907A_PN2907A_PZT2907A.pdf | Q_PNP_CBE | 2 | Q2 | 512-PN2907BU
27 | 8 | R21 R22 R23 R24 | R21 R22 R23 R24 | 330 | 4 | S330CACT-ND | Stackpole Electronics Inc | RNMF14FTC330R | R_Axial_DIN0204_L3.6mm_D1.6mm_P5.08mm_Horizontal | Resistor, US symbol | https://www.seielect.com/catalog/sei-rnf_rnmf.pdf | R_US | 8 | R21 R22 R23 R24
28 | 2 | R17 | R17 | 1K | 1 | RNF14FTD1K00CT-ND | Stackpole Electronics Inc | RNF14FTD1K00 | R_Axial_DIN0207_L6.3mm_D2.5mm_P7.62mm_Horizontal | Resistor, US symbol | https://www.seielect.com/catalog/sei-rnf_rnmf.pdf | R_US | 2 | R17
29 | 4 | R29 R30 | R29 R30 | 2K | 2 | RNF14FTD2K00CT-ND | Stackpole Electronics Inc | RNF14FTD2K00 | R_Axial_DIN0207_L6.3mm_D2.5mm_P7.62mm_Horizontal | Resistor, US symbol | https://www.seielect.com/catalog/sei-rnf_rnmf.pdf | R_US | 4 | R29 R30
30 | 52 | R1 R2 R3 R6 R7 R8 R9 R10 R11 R12 R13 R14 R16 R18 R19 R20 R25 R26 R27 R28 R31 R32 R35 R36 R37 R39 | R1 R2 R3 R6 R7 R8 R9 R10 R11 R12 R13 R14 R16 R18 R19 R20 R25 R26 R27 R28 R31 R32 R35 R36 R37 R39 | 10K | 26 | RNF14FTD10K0CT-ND | Stackpole Electronics Inc | RNF14FTD10K0 | R_Axial_DIN0207_L6.3mm_D2.5mm_P7.62mm_Horizontal | Resistor, US symbol | https://www.seielect.com/catalog/sei-rnf_rnmf.pdf | R_US | 52 | R1 R2 R3 R6 R7 R8 R9 R10 R11 R12 R13 R14 R16 R18 R19 R20 R25 R26 R27 R28 R31 R32 R35 R36 R37 R39
31 | 4 | R15 R38 | R15 R38 | 100K | 2 | RNF14FTD100KCT-ND | Stackpole Electronics Inc | RNF14FTD100K | R_Axial_DIN0207_L6.3mm_D2.5mm_P7.62mm_Horizontal | Resistor, US symbol | https://www.seielect.com/catalog/sei-rnf_rnmf.pdf | R_US | 4 | R15 R38
32 | 4 | R33 R34 | R33 R34 | 1M | 2 | RNF14FTD1M00CT-ND | Stackpole Electronics Inc | RNF14FTD1M00 | R_Axial_DIN0207_L6.3mm_D2.5mm_P7.62mm_Horizontal | Resistor, US symbol | https://www.seielect.com/catalog/sei-rnf_rnmf.pdf | R_US | 4 | R33 R34
33 | 2 | R4 | R4 | 316K 1% | 1 | RNF14FTD316KCT-ND | Stackpole Electronics Inc | RNF14FTD316K | R_Axial_DIN0207_L6.3mm_D2.5mm_P7.62mm_Horizontal | Resistor, US symbol | https://www.seielect.com/catalog/sei-rnf_rnmf.pdf | R_US | 2 | R4
34 | 2 | R5 | R5 | 412K 1% | 1 | RNF14FTD412KCT-ND | Stackpole Electronics Inc | RNF14FTD412K | R_Axial_DIN0207_L6.3mm_D2.5mm_P7.62mm_Horizontal | Resistor, US symbol | https://www.seielect.com/catalog/sei-rnf_rnmf.pdf | R_US | 2 | R5
35 | 16 | SW1 SW2 SW3 SW4 SW5 SW6 SW7 SW8 | SW1 SW2 SW3 SW4 SW5 SW6 SW7 SW8 | BTN | 8 | SW400-ND | Omron Electronics Inc-EMC Div | B3F-1000 | SW_B3F-10xx | Push button switch, generic, two pins | https://omronfs.omron.com/en_US/ecb/products/pdf/en-b3f.pdf | SW_Push_2-4 | 16 | SW1 SW2 SW3 SW4 SW5 SW6 SW7 SW8 | 653-B3F-1000
36 | 2 | SW9 | SW9 | Reset | 1 | SW950-ND | Omron Electronics Inc-EMC Div | B3F-1006 | SW_B3F-10xx | Push button switch, generic, two pins | https://omronfs.omron.com/en_US/ecb/products/pdf/en-b3f.pdf | SW_Push_1-3 | 2 | SW9 | 653-B3F-1006
37 | 2 | U7 | U7 | 25LC1024-I/P | 1 | 25LC1024-I/P-ND | Microchip Technology | 25LC1024-I/P | DIP-8_W7.62mm | SPI Serial EEPROM, DIP-8/SOIC-8/TSSOP-8 | https://ww1.microchip.com/downloads/en/DeviceDoc/22064D.pdf | 25LCxxx | 2 | U7 | 579-25LC1024-I/P
38 | 2 | U5 | U5 | ATmega328P-PU | 1 | ATMEGA328P-PU-ND | Microchip Technology | ATMEGA328P-PU | DIP-28_W7.62mm |  | http://ww1.microchip.com/downloads/en/DeviceDoc/ATmega328_P%20AVR%20MCU%20with%20picoPower%20Technology%20Data%20Sheet%2040001984A.pdf | ATmega328P-PU-UserLibrary | 2 | U5 | 556-ATMEGA328P-PU
39 | 2 | U1 | U1 | CD74HC151E | 1 | 296-25973-5-ND | Texas Instruments | CD74HC151E | DIP-16_W7.62mm |  | https://www.ti.com/lit/ds/symlink/cd74hc151.pdf | CD74HC151E-EZLayout | 2 | U1 | 595-CD74HC151E
40 | 2 | U4 | U4 | LT1303CN8-5#PBF | 1 | LT1303CN8-5#PBF-ND | Analog Devices Inc. | LT1303CN8-5#PBF | PDIP-8_N |  | https://www.analog.com/media/en/technical-documentation/data-sheets/lt1303.pdf | LT1303CN8-5#PBF-UserLibrary | 2 | U4 | 584-LT1303CN8-5#PBF
41 | 2 | U8 | U8 | MAX4466EXK | 1 | MAX4466EXK+CT-ND | Maxim Integrated | MAX4466EXK+T | SOT65P210X110-5N |  | https://datasheets.maximintegrated.com/en/ds/MAX4465-MAX4469.pdf | MAX4466EXK | 2 | U8 | 700-MAX4466EXKT
42 | 2 | U6 | U6 | MCP3201 | 1 | MCP3201-CI/P-ND | Microchip Technology | MCP3201-CI/P | DIP-8_W7.62mm |  | https://ww1.microchip.com/downloads/en/DeviceDoc/21290F.pdf | MCP3201_TriStateMISO-UserLibrary | 2 | U6 | 579-MCP3201-CI/P
43 | 2 | U3 | U3 | RN4871-I/RM140 | 1 | 150-RN4871-I/RM140-ND | Microchip Technology | RN4871-I/RM140 | Microchip_RN4871 | Bluetooth Low Energy 4.2 Module | https://ww1.microchip.com/downloads/en/DeviceDoc/RN4870-71-Data-Sheet-DS50002489E.pdf | RN4871 | 2 | U3 | 579-RN4871-I/RM140 | https://ww1.microchip.com/downloads/en/DeviceDoc/RN4870-71-Bluetooth-Low-Energy-Module-User-Guide-DS50002466C.pdf
44 | 2 | U2 | U2 | TSR_1-2433 | 1 | 1951-2742-ND | Traco Power | TSR 1-2433 | Converter_DCDC_TRACO_TSR-1_THT | 1A step-down regulator module, fixed 3.3V output voltage, 5-36V input voltage, -40°C to +85°C temperature range, TO-220 compatible LM78xx replacement | https://www.tracopower.com/sites/default/files/products/datasheets/tsr1_datasheet.pdf | TSR_1-2433 | 2 | U2 | 495-TSR-1-2433
45 | 2 | Y1 | Y1 | 16MHz | 1 | 887-1244-ND | TXC CORPORATION | 9B-16.000MEEJ-B | Crystal_HC49-U_Vertical | Two pin crystal | http://www.txccrystal.com/images/pdf/9b-accuracy.pdf | Crystal | 2 | Y1 | 717-9B-16.000MEEJ-B
Component Groups: | 45
Component Count: | 110
Fitted Components: | 110
Number of PCBs: | 2
Total components: | 220
Schematic Version: | 1.3
Schematic Date: | 2021-03-11
PCB Variant: | udefault
BoM Date: | 3/11/2021 11:59:10 PM
Schematic Source: | ShotTimer.sch
KiCad Version: | Eeschema (5.1.9)-1

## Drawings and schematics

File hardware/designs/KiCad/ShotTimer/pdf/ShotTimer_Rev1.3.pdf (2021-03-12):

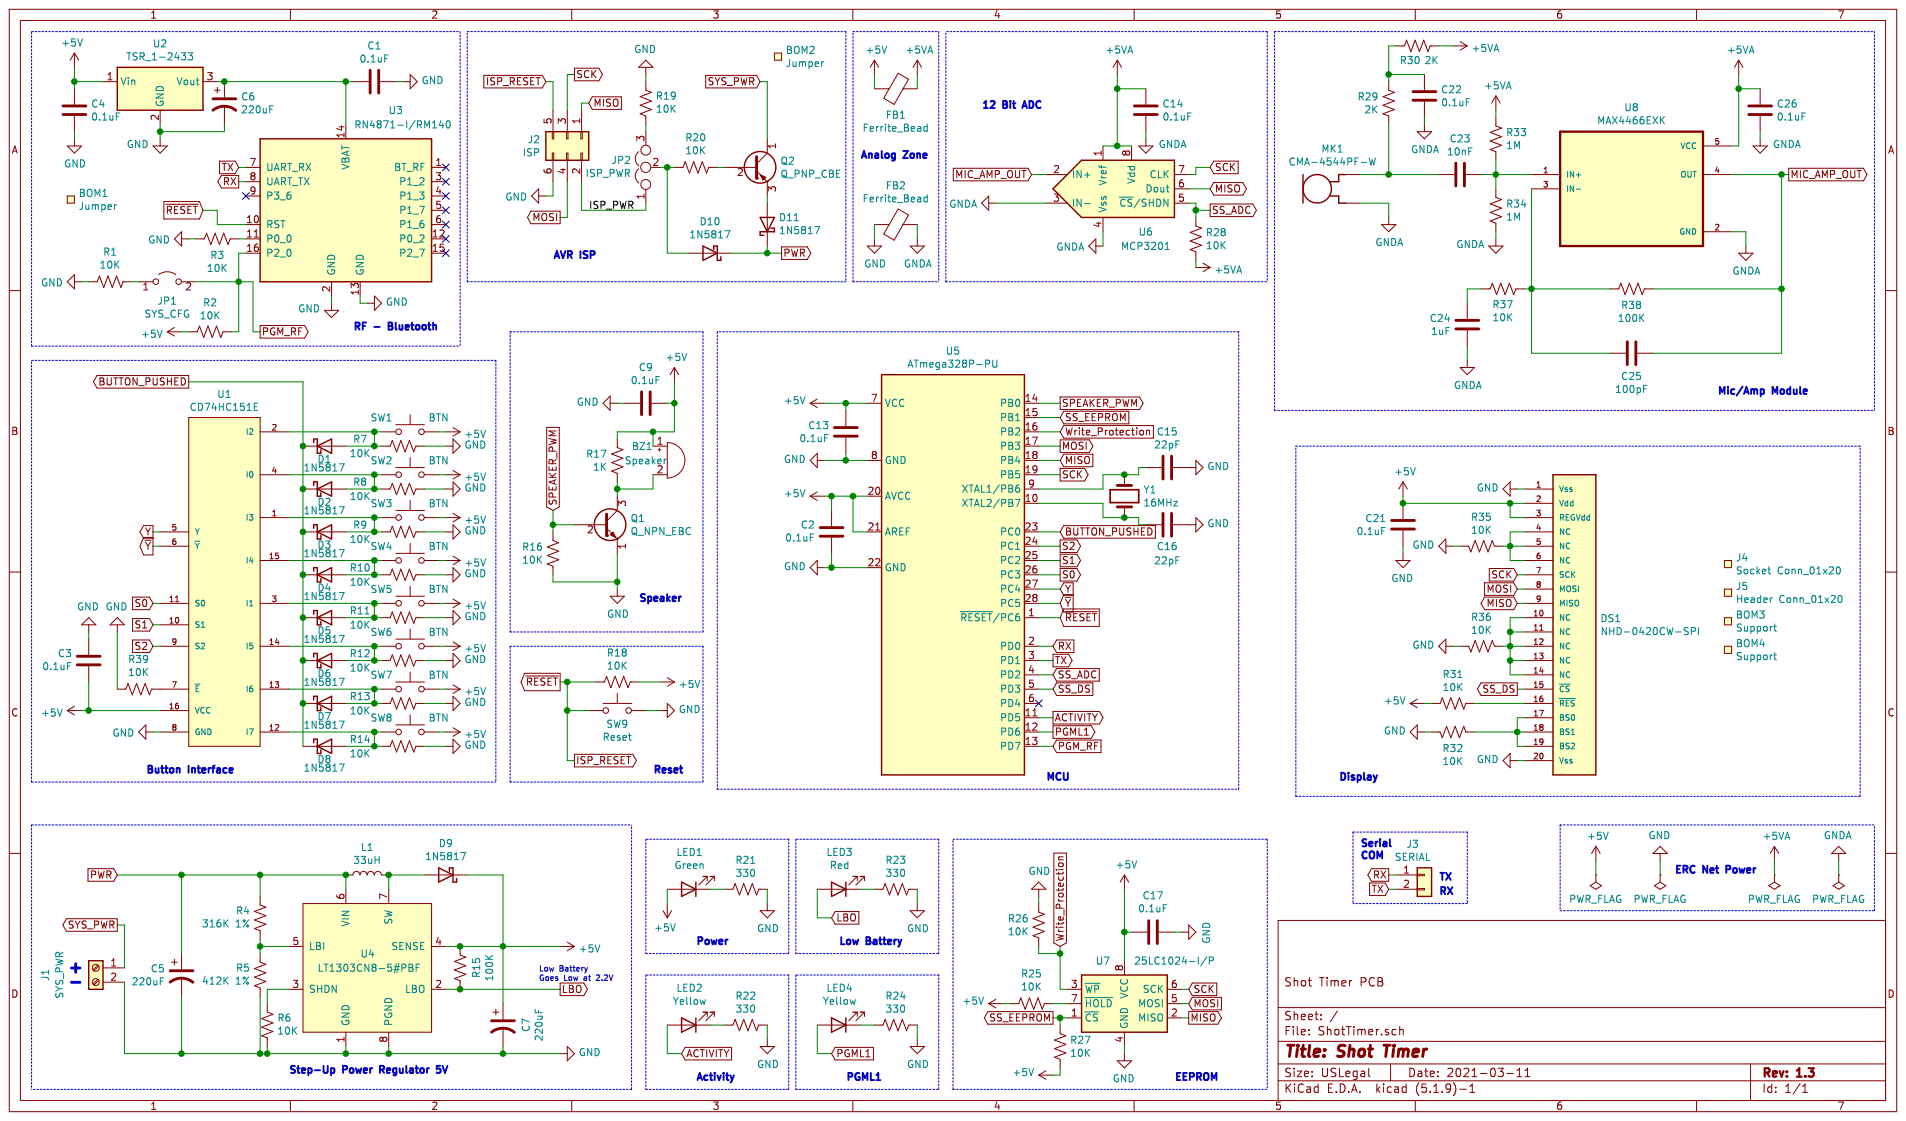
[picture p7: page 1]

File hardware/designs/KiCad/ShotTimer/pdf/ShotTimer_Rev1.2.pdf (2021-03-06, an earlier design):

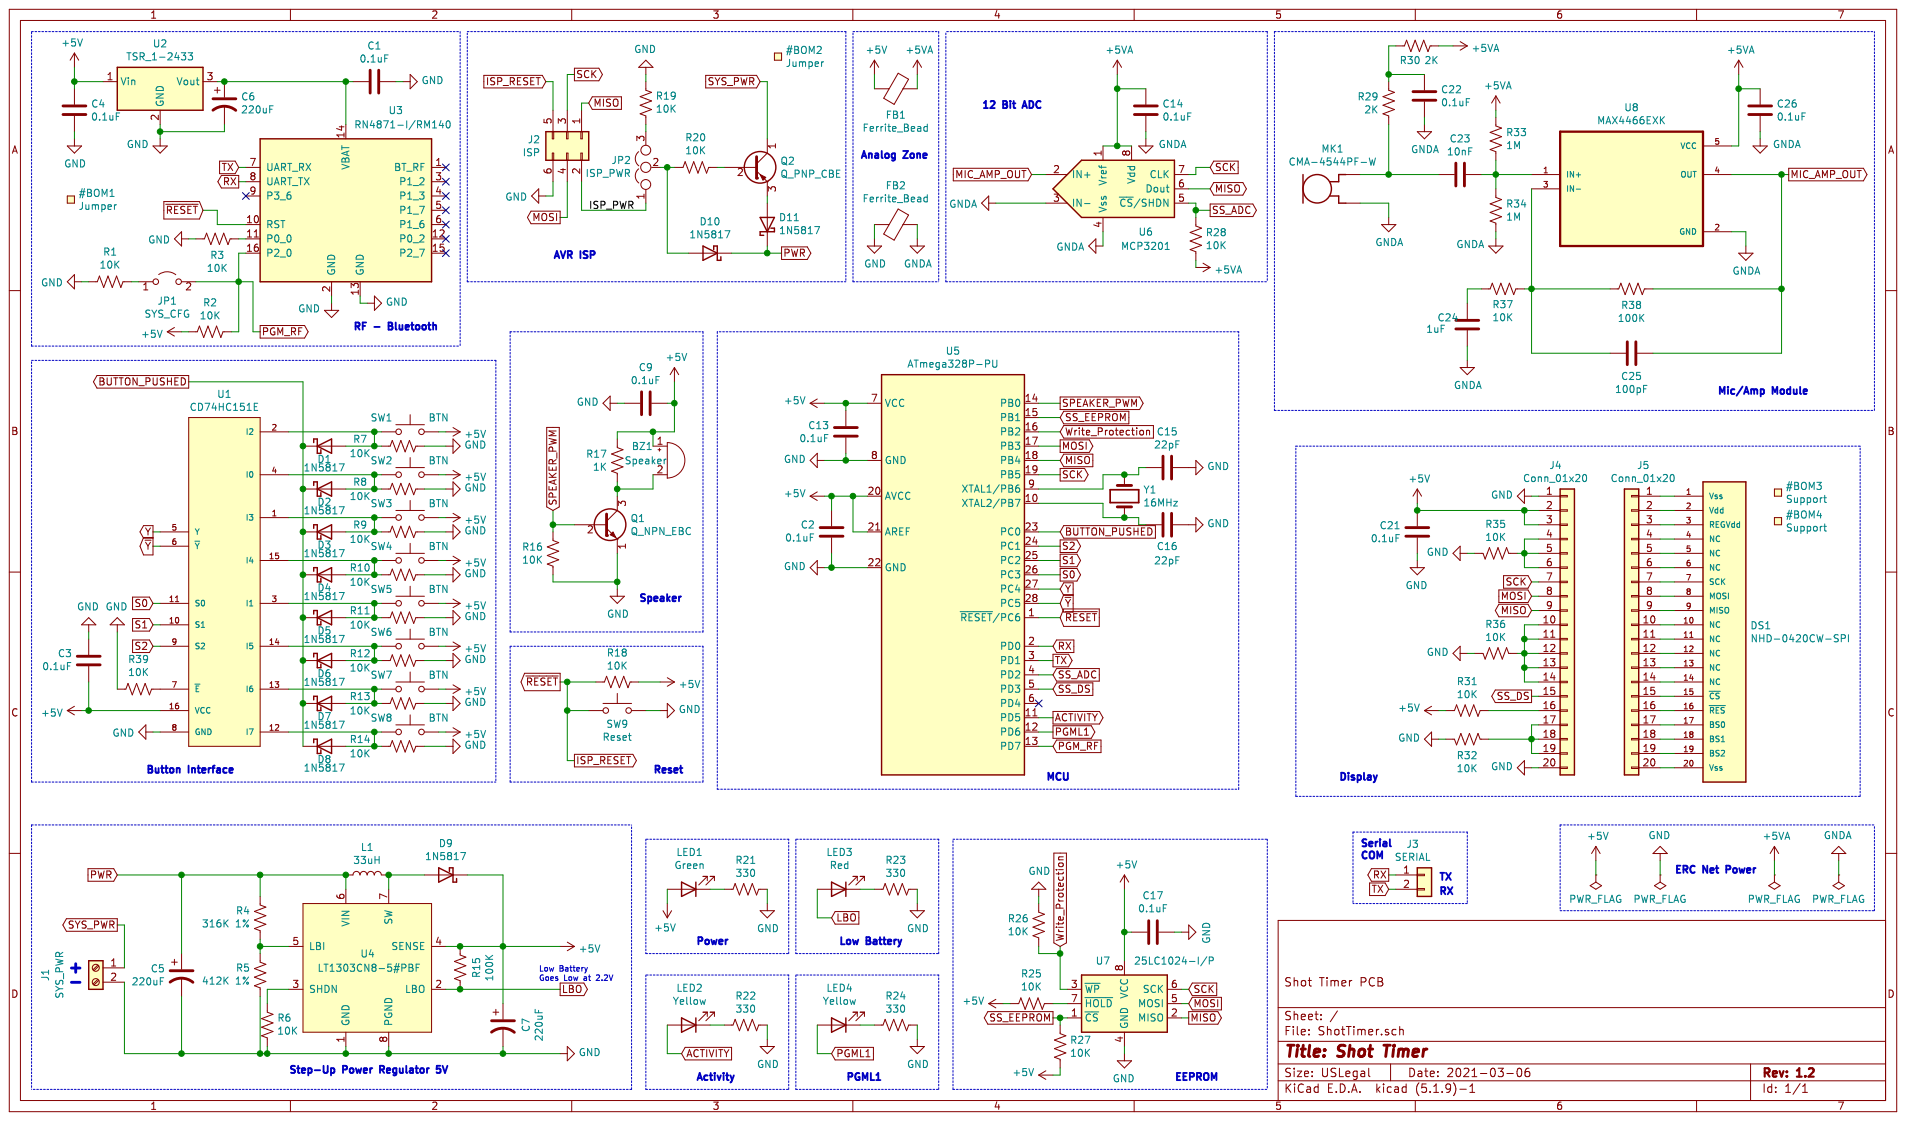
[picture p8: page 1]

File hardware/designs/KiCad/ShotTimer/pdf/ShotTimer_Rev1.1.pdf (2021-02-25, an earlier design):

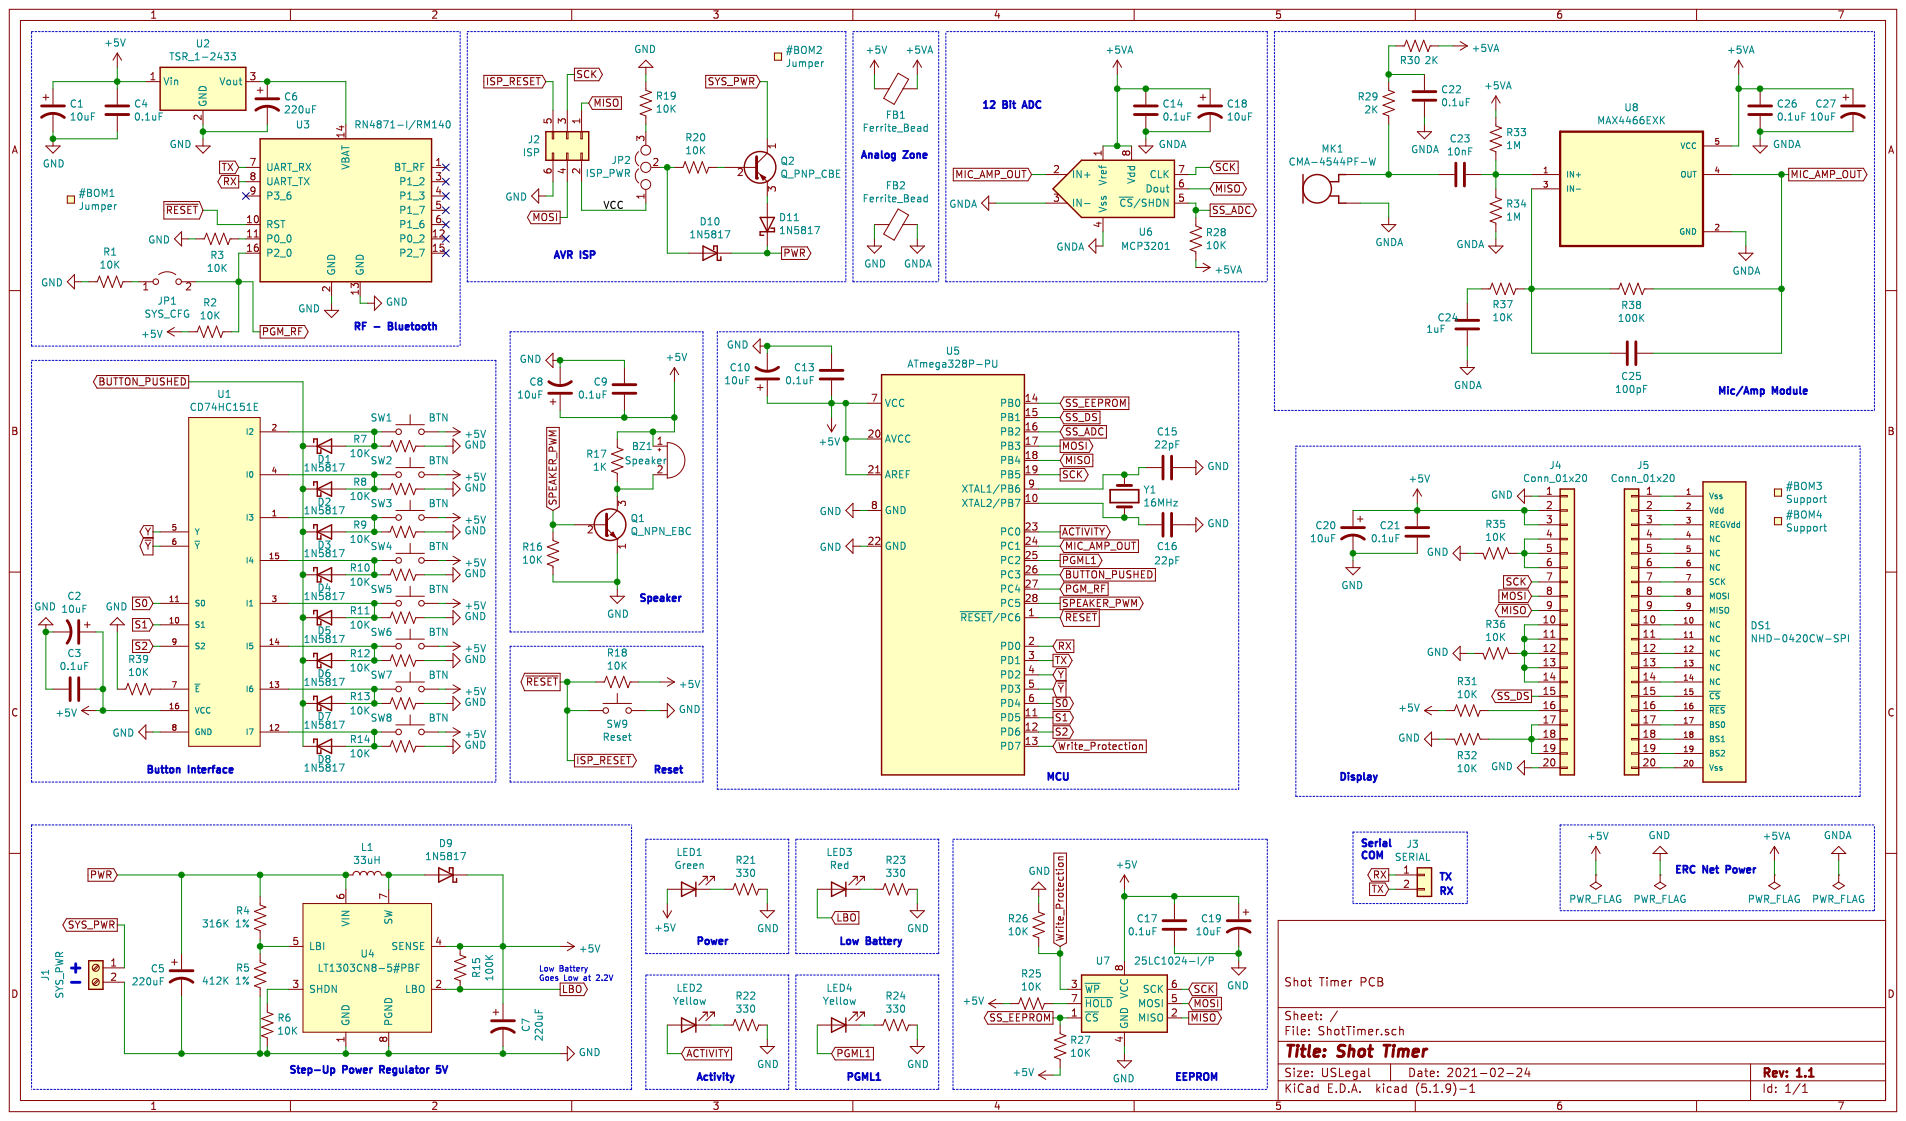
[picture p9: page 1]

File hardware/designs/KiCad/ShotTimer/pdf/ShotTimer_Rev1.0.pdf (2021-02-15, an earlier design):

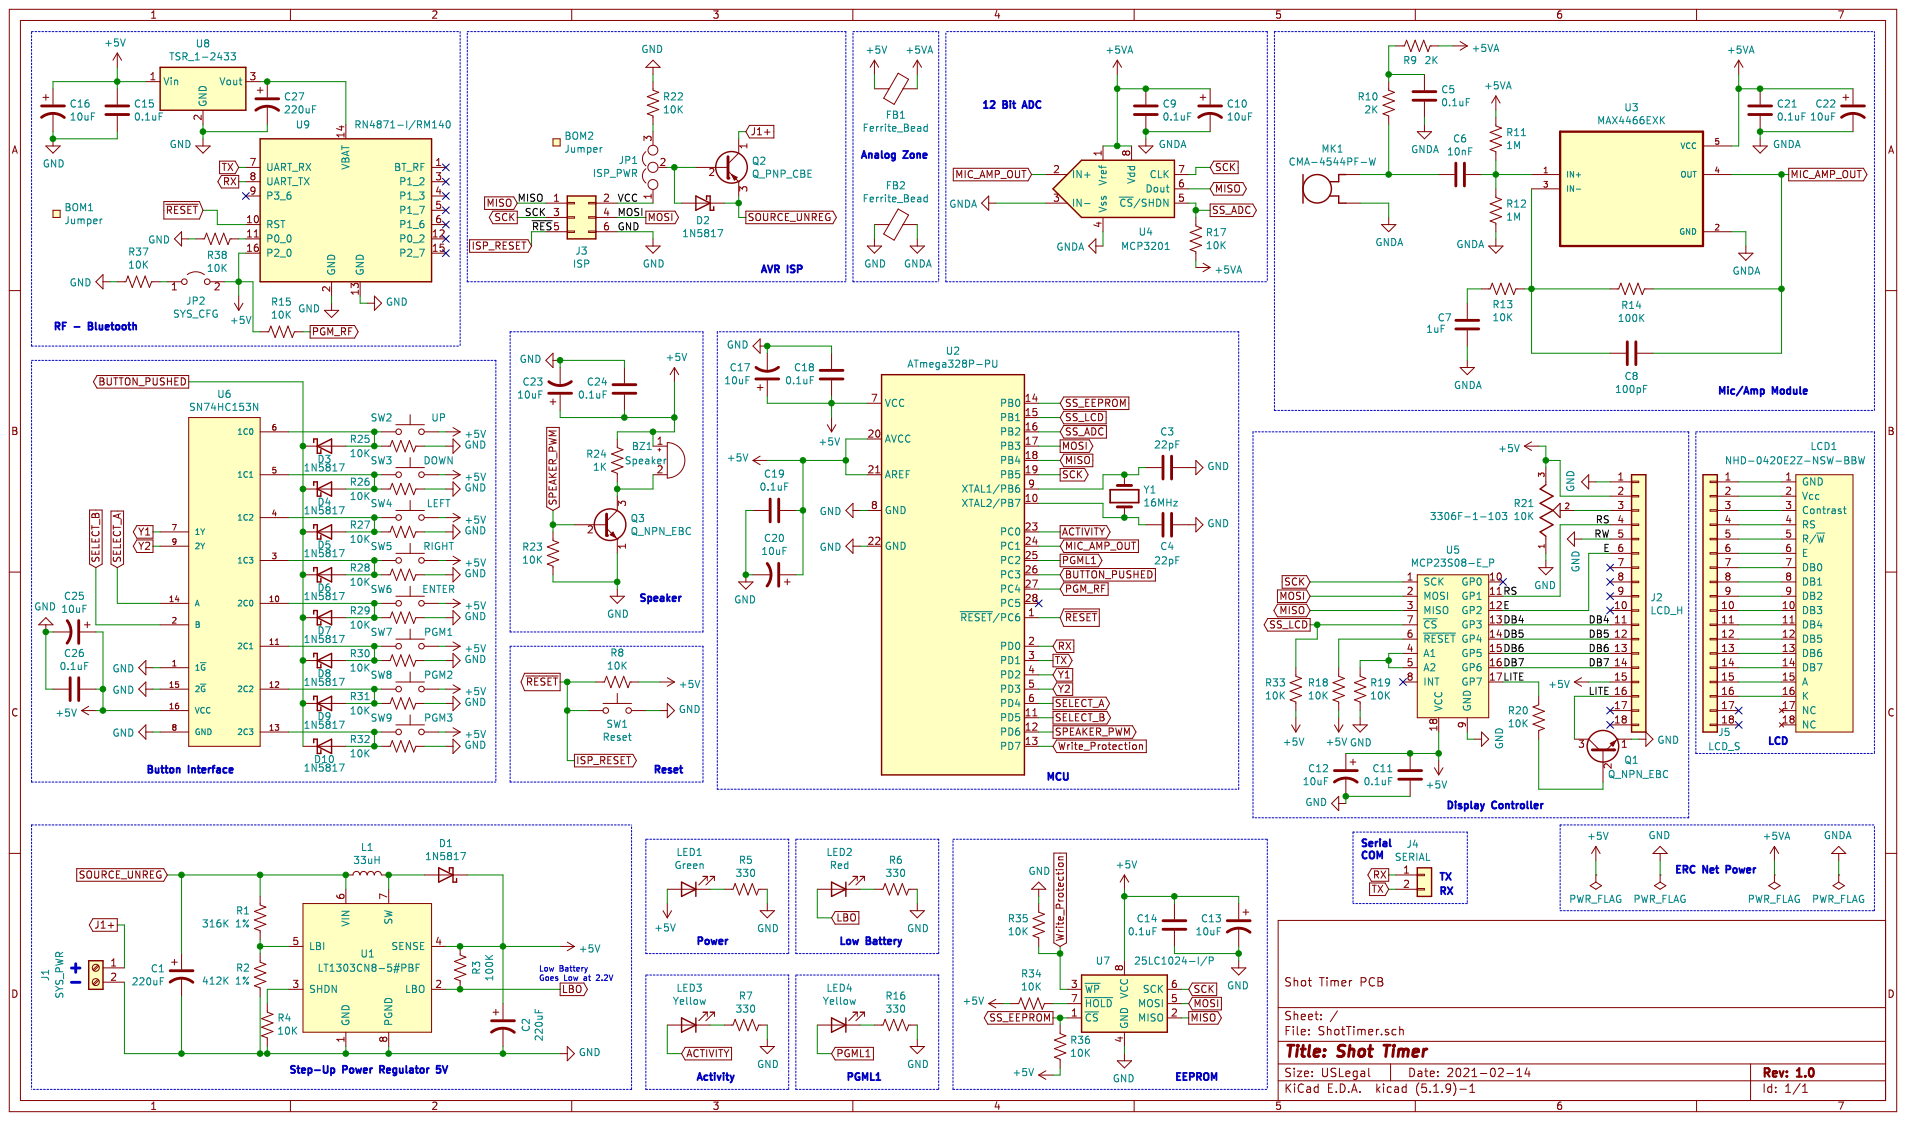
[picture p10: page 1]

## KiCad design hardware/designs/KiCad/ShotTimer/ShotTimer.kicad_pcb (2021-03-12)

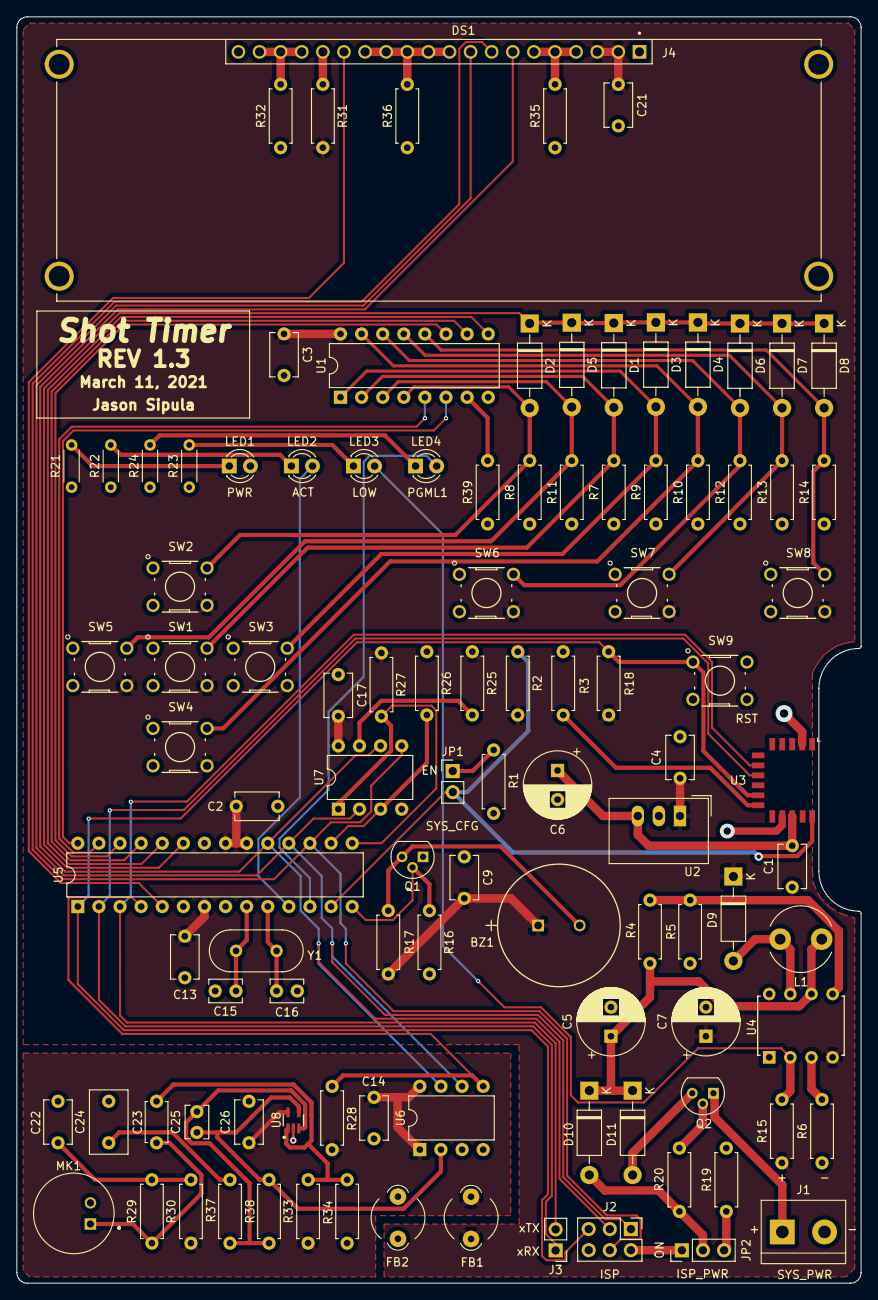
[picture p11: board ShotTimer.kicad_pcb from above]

Board: 2 copper layers, 101.6 x 152.4 mm, 104 parts (0 on the bottom side), 65 nets.

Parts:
BZ1: Speaker; PS1420P02CT
C1, C2, C3, C4, C9, C13, C14, C17, C21, C22, C26: 0.1uF; C_Disc_D5.1mm_W3.2mm_P5.00mm
C5, C6, C7: 220uF; CP_Radial_D8.0mm_P3.50mm
C15, C16: 22pF; C_Disc_D3.8mm_W2.6mm_P2.50mm
C23: 10nF; C_Disc_D4.7mm_W2.5mm_P5.00mm
C24: 1uF; C_Disc_D7.5mm_W4.4mm_P5.00mm
C25: 100pF; C_Disc_D3.8mm_W2.6mm_P2.50mm
D1, D2, D3, D4, D5, D6, D7, D8, D9, D10, D11: 1N5817; D_DO-41_SOD81_P10.16mm_Horizontal
DS1: NHD-0420CW-SPI; NHD_NHD-0420CW-AG3
FB1, FB2: Ferrite_Bead; LairdTech_28C0236-0JW-10
J1: SYS_PWR; TerminalBlock_bornier-2_P5.08mm
J2: ISP; PinHeader_2x03_P2.54mm_Vertical
J3: SERIAL; PinHeader_1x02_P2.54mm_Vertical
JP1: SYS_CFG; PinHeader_1x02_P2.54mm_Vertical
JP2: ISP_PWR; PinHeader_1x03_P2.54mm_Vertical
L1: 33uH; L_Radial_D7.8mm_P5.00mm_Fastron_07HCP
LED1: Green; LED_D3.0mm
LED2, LED4: Yellow; LED_D3.0mm
LED3: Red; LED_D3.0mm
MK1: CMA-4544PF-W; MIC_CMA-4544PF-W
Q1: Q_NPN_EBC; TO-92
Q2: Q_PNP_CBE; TO-92
R1, R2, R3, R6, R7, R8, R9, R10, R11, R12, R13, R14, R16, R18, R19, R20, R25, R26, R27, R28, R31, R32, R35, R36, R37, R39: 10K; R_Axial_DIN0207_L6.3mm_D2.5mm_P7.62mm_Horizontal
R4: 316K 1%; R_Axial_DIN0207_L6.3mm_D2.5mm_P7.62mm_Horizontal
R5: 412K 1%; R_Axial_DIN0207_L6.3mm_D2.5mm_P7.62mm_Horizontal
R15, R38: 100K; R_Axial_DIN0207_L6.3mm_D2.5mm_P7.62mm_Horizontal
R17: 1K; R_Axial_DIN0207_L6.3mm_D2.5mm_P7.62mm_Horizontal
R21, R22, R23, R24: 330; R_Axial_DIN0204_L3.6mm_D1.6mm_P5.08mm_Horizontal
R29, R30: 2K; R_Axial_DIN0207_L6.3mm_D2.5mm_P7.62mm_Horizontal
R33, R34: 1M; R_Axial_DIN0207_L6.3mm_D2.5mm_P7.62mm_Horizontal
SW1, SW2, SW3, SW4, SW5, SW6, SW7, SW8: BTN; SW_B3F-10xx
SW9: Reset; SW_B3F-10xx
U1: CD74HC151E; DIP-16_W7.62mm
U2: TSR_1-2433; Converter_DCDC_TRACO_TSR-1_THT
U3: RN4871-I/RM140; Microchip_RN4871
U4: LT1303CN8-5#PBF; PDIP-8_N
U5: ATmega328P-PU; DIP-28_W7.62mm
U6: MCP3201; DIP-8_W7.62mm
U7: 25LC1024-I/P; DIP-8_W7.62mm
U8: MAX4466EXK; SOT65P210X110-5N
Y1: 16MHz; Crystal_HC49-U_Vertical

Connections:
+5V: BZ1.1, C2.2, C3.1, C4.1, C7.1, C9.2, C13.1, C17.2, C21.1, D9.1, DS1.2, DS1.3, FB1.2, LED1.2, R2.2, R15.1, R17.1, R18.1, R25.1, R27.2, R31.2, SW1.4, SW2.4, SW3.4, SW4.4, SW5.4, SW6.4, SW7.4, SW8.4, U1.16, U2.1, U4.4, U5.7, U5.20, U5.21, U7.8
+5VA: C14.1, C26.1, FB1.1, R28.2, R30.1, R33.1, U6.1, U6.8, U8.5
/ISP_PWR: J2.2, JP2.1
ACTIVITY: LED2.2, U5.11
BUTTON_PUSHED: D1.1, D2.1, D3.1, D4.1, D5.1, D6.1, D7.1, D8.1, U5.23
GND: C1.1, C2.1, C3.2, C4.2, C5.2, C6.2, C7.2, C9.1, C13.2, C15.1, C16.1, C17.1, C21.2, DS1.1, DS1.20, FB2.2, J1.2, J2.6, Q1.1, R1.1, R3.2, R5.1, R6.1, R7.1, R8.1, R9.1, R10.1, R11.1, R12.1, R13.1, R14.1, R16.2, R19.2, R21.1, R22.1, R23.1, R24.1, R26.1, R32.1, R35.1, R36.1, R39.1, SW9.3, U1.8, U2.2, U3.2, U3.13, U4.1, U4.8, U5.8, U5.22, U7.4
GNDA: C14.2, C22.2, C24.2, C26.2, FB2.1, MK1.2, R34.2, U6.3, U6.4, U8.2
ISP_RESET: J2.5, R18.2, SW9.1, U3.10, U5.1
LBO: LED3.2, R15.2, U4.2
MIC_AMP_OUT: C25.1, R38.1, U6.2, U8.4
MISO: DS1.9, J2.1, U5.18, U6.6, U7.2
MOSI: DS1.8, J2.4, U5.17, U7.5
unnamed: BZ1.2, Q1.3, R17.2
unnamed: C1.2, C6.1, U2.3, U3.14
unnamed: C15.2, U5.9, Y1.1
unnamed: C16.2, U5.10, Y1.2
unnamed: C22.1, R29.1, R30.2
unnamed: C23.1, R33.2, R34.1, U8.1
unnamed: C23.2, MK1.1, R29.2
unnamed: C24.1, R37.1
unnamed: C25.2, R37.2, R38.2, U8.3
unnamed: D1.2, R7.2, SW1.2, U1.2
unnamed: D2.2, R8.2, SW2.2, U1.4
unnamed: D3.2, R9.2, SW3.2, U1.1
unnamed: D4.2, R10.2, SW4.2, U1.15
unnamed: D5.2, R11.2, SW5.2, U1.3
unnamed: D6.2, R12.2, SW6.2, U1.14
unnamed: D7.2, R13.2, SW7.2, U1.13
unnamed: D8.2, R14.2, SW8.2, U1.12
unnamed: D9.2, L1.2, U4.7
unnamed: D10.2, JP2.2, R20.1
unnamed: D11.2, Q2.3
unnamed: DS1.4, DS1.5, DS1.6, R35.2
unnamed: DS1.10, DS1.11, DS1.12, DS1.13, DS1.14, R36.2
unnamed: DS1.16, R31.1
unnamed: DS1.17, DS1.18, DS1.19, R32.2
unnamed: JP1.1, R1.2
unnamed: JP2.3, R19.1
unnamed: LED1.1, R21.2
unnamed: LED2.1, R22.2
unnamed: LED3.1, R23.2
unnamed: LED4.1, R24.2
unnamed: Q2.2, R20.2
unnamed: R3.1, U3.11
unnamed: R4.1, R5.2, U4.5
unnamed: R6.2, U4.3
unnamed: R25.2, U7.7
unnamed: R39.2, U1.7
PGML1: LED4.2, U5.12
PGM_RF: JP1.2, R2.1, U3.16, U5.13
PWR: C5.1, D10.1, D11.1, L1.1, R4.2, U4.6
RX: J3.1, U3.8, U5.2
S0: U1.11, U5.26
S1: U1.10, U5.25
S2: U1.9, U5.24
SCK: DS1.7, J2.3, U5.19, U6.7, U7.6
SPEAKER_PWM: Q1.2, R16.1, U5.14
SS_ADC: R28.1, U5.4, U6.5
SS_DS: DS1.15, U5.5
SS_EEPROM: R27.1, U5.15, U7.1
SYS_PWR: J1.1, Q2.1
TX: J3.2, U3.7, U5.3
Write_Protection: R26.2, U5.16, U7.3
Y: U1.5, U5.27
~Y: U1.6, U5.28

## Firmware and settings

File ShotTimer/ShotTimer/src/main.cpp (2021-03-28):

/************************************************************************/
/* We're hooked into the Arduino main(), just pass calls into ShotTImer */
/************************************************************************/

#include <Arduino.h>

#include "ShotTimer.h"

void setup()
{
	ShotTimer::setup();
}

void loop()
{
	ShotTimer::loop();
}

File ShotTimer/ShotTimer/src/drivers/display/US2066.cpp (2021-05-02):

/* 
* US2066.cpp
*
* Created: 3/27/2021
* Author: Jason Sipula
*/


#include "drivers/display/US2066.h"

US2066::US2066(uint8_t cols, uint8_t lines, uint8_t cs_pin, uint32_t sck) :
	_COLS(cols),
	_LINES(lines),
	_CS_PIN(cs_pin),
	_SCK(sck > _MAX_SCK ? _MAX_SCK : sck)
{
	pinMode(_CS_PIN, OUTPUT);
	digitalWrite(_CS_PIN, HIGH); // pull CS high to disable chip
		
}

US2066::~US2066()
{
	digitalWrite(_CS_PIN, HIGH); // pull CS high to disable chip
}

const uint32_t US2066::MaxSupportedSCK()
{
	return _MAX_SCK;
}

void US2066::init()
{
	_row_offsets[0] = OFFSET_LINE_1;
	_row_offsets[1] = _LINES == 2 ? OFFSET_LINE_3 : OFFSET_LINE_2; // when the display has only 2 lines, offset line 3 is used as line 2
	_row_offsets[2] = OFFSET_LINE_3;
	_row_offsets[3] = OFFSET_LINE_4;
	
	/*
	 * even though the following settings are generally the Power On Reset values for the controller,
	 * the init() function sets them anyway to act as a sort-of soft reset
	 */
	
	// default configuration
	_displayFunction = FUNCTION_SET | FOUR_LINE_DISPLAY | NORMAL_HEIGHT_FONT;
	_displayControl = DISPLAY_CONTROL | DISPLAY_OFF | CURSOR_OFF | BLINK_OFF;
	_displayMode = ENTRY_MODE_SET | ENTRY_RIGHT | ENTRY_DISABLE_SHIFT;
	
	_sendCommandStartByte();
	
	/*
	 * Page 21 of the NHD-0420CW documentation describes a typical initialization routine.
	 * Reference commands with the command table found in the US2066 documentation pages 26 - 31.
	 */
	_send(_displayFunction | ENABLE_EXTENDED_COMMAND_SET);									// function set (extended command set)
	
	_send(FUNCTION_SELECTION_A);															// function selection A
	_sendDataStartByte(); // function A always requires a data packet next
	_send(REGULATE_5V_MODE);																// enable 5v mode
	_sendCommandStartByte(); // back to commands
	
	_send(_displayFunction & ~ENABLE_EXTENDED_COMMAND_SET);									// function set (fundamental command set), exit extended command set
	_send(_displayControl);																	// display off, cursor off, blink off
	
	_send(_displayFunction | ENABLE_EXTENDED_COMMAND_SET);									// function set (extended command set)
	
	_send(OLED_CHARACTERIZATION | ENABLE_OLED_COMMAND_SET);									// OLED command set enabled
	_send(SEG_PIN_ALTERNATIVE | DISABLE_SEG_LEFT_RIGHT_REMAP);								// default Sequential SEG & left/right
	_send(FUNCTION_SELECTION_C);															// function selection C
	_send(GPIO_INPUT_DISABLED);																// disable GPIO on the controller, we're not using it
	_send(SET_CONTRAST_CONTROL);															// set contrast
	_send(DEFAULT_CONTRAST);																// default is POR value of 0x7F
	_send(SET_PHASE_LENGTH);																// set phase length
	_send(DEFAULT_PHASE_1_PERIOD | DEFAULT_PHASE_2_PERIOD);									// default is POR values of Phase 1: 16 dsp clks | Phase 2: 7 dsp clks
	_send(SET_VCOMH_DESELECT_LEVEL);														// set VCOMH deselect level
	_send(DESELECT_LEVEL_1_00);																// default is POR value of ~1.0 x Vcc
	_send(OLED_CHARACTERIZATION & ~ENABLE_OLED_COMMAND_SET);								// OLED command set disabled, back to extended function set
	
	_send(EXTENDED_FUNCTION_SET | FOUR_LINE_OR_LESS_MODE);									// 4 line display mode, default no inverting cursor and 5 dot font width
	_send(EXTENDED_ENTRY_MODE_SET | BIDIRECTION_COMMON_ASC | BIDIRECTION_SEGMENT_ASC);		// COM SEG Direction (COM0 -> COM31, SEG0 -> SEG99), left to right on display
	
	_send(FUNCTION_SELECTION_B);															// function selection B
	_sendDataStartByte(); // function B always requires a data packet
	_send(SELECT_CHARACTER_ROM_A);															// selection Character ROM A
	_sendCommandStartByte(); // back to commands
	
	_send(_displayFunction & ~ENABLE_EXTENDED_COMMAND_SET);									// exit extended command set, back to function set (fundamental command set)
	
	// tidy up, then turn the screen on
	clear();
	displayOn();
	delay(100); // give it some time to turn on
	
}

void US2066::clear()
{
	_sendCommand(CLEAR_DISPLAY);
	delay(100);
}

void US2066::home()
{
	_sendCommand(RETURN_HOME);
	delay(100);
}

void US2066::setCursor(uint8_t col, uint8_t row)
{
	if (row > _LINES) row = _LINES;
	else if (row < 0) row = 0;
	if (col > _COLS) col = _COLS;
	else if (col < 0) col = 0;
	
	command(SET_DDRAM_ADDR | (col + _row_offsets[row]));
}

void US2066::displayOn()
{
	_displayControl |= DISPLAY_ON;
	command(_displayControl);
}

void US2066::displayOff()
{
	_displayControl &= ~DISPLAY_ON;
	command(_displayControl);
}

void US2066::blinkOn()
{
	_displayControl |= BLINK_ON;
	command(_displayControl);
}

void US2066::blinkOff()
{
	_displayControl &= ~BLINK_ON;
	command(_displayControl);
}

void US2066::cursorOn()
{
	_displayControl |= CURSOR_ON;
	command(_displayControl);
}

void US2066::cursorOff()
{
	_displayControl &= ~CURSOR_ON;
	command(_displayControl);
}

void US2066::scrollLeft()
{
	command(CURSOR_SHIFT | DISPLAY_MOVE | LEFT_MOVE);
}

void US2066::scrollRight()
{
	command(CURSOR_SHIFT | DISPLAY_MOVE | RIGHT_MOVE);
}

void US2066::leftToRight()
{
	_displayMode |= ENTRY_RIGHT;
	command(_displayMode);
}

void US2066::rightToLeft()
{
	_displayMode &= ~ENTRY_RIGHT;
	command(_displayMode);
}

void US2066::autoScrollOn()
{
	_displayMode |= ENTRY_ENABLE_SHIFT;
	command(_displayMode);
}

void US2066::autoScrollOff()
{
	_displayMode &= ~ENTRY_ENABLE_SHIFT;
	command(_displayMode);
}

void US2066::createChar(uint8_t location, uint8_t charmap[])
{
	location &= 0x07; // we only have 8 locations, 0 - 7
	command(SET_CGRAM_ADDR | ( location << 3 ));
	for (int i = 0; i < 8; i++) {
		write(charmap[i]);
	}
}

void US2066::command(uint8_t data)
{
	_sendCommandStartByte();
	_send(data);
}

size_t US2066::write(uint8_t data)
{
	_send(data);
	return 1; // assume success, report 1 byte written to satisfy <Print.h>
}

size_t US2066::write(const uint8_t *buffer, size_t size)
{
	_sendDataStartByte(); // never a command if we come through this function
	
	while (size--) {
		write(*buffer++);
	}
	
	return size; // assume success, report 'size' bytes written to satisfy <Print.h>
}

void US2066::open()
{
	if (!_spiTransactionStarted) {
		// begin SPI transaction with US2066 settings
		SPI.beginTransaction(SPISettings(_SCK, _BIT_ORDER, _DATA_MODE));
		digitalWrite(_CS_PIN, LOW); // take CS low to start command/data send
		_spiTransactionStarted = true;
	}
}

void US2066::close()
{
	digitalWrite(_CS_PIN, HIGH); // take CS high to end send
	SPI.endTransaction();
	_spiTransactionStarted = false;
}

void US2066::_sendCommandStartByte()
{
	SPI.transfer( START_BYTE | SEND_COMMAND );
}

void US2066::_sendDataStartByte()
{
	SPI.transfer( START_BYTE | SEND_DATA );
}
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

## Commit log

2018-08-01 Use the new shottimer.h hooks, and point out this file is essentially a standard run-of-the-mill Arduino project main.cpp file
2018-08-07 Revamped debug system, now it's header-only, and has better utility by providing an option to print milliseconds, function name, file name and line number.
2018-08-07 Add headers to header file, and add new sample code
2018-08-07 interface for audio device drivers, such as mic's and amps
2018-08-07 Initial driver implementation - borrowed from adafruit sample code
2020-07-27 tuned to reject detected samples, so we don't pollute our levels. tune sample window
2020-07-27 reject all readings below decibel threshold value, but record their value to enable background noise level smoothing.
    [MAX4466.hpp]
2020-07-27 Breadboard design so far
    [Breadboard_Design.fzz]
2020-07-28 update design
    [Breadboard_Design.fzz]
2020-09-09 sync fritzing designs... slacker
    [Breadboard_Design.fzz, Breadboard_Design_v2.fzz]
2020-09-09 sync changes... including refactor, template the circular queue so we can accept generic types, test various methods for calculating dbA from our audio sensor, but nothing is right so far. have a few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
2020-09-09 not working linked list. doing it the hard, err... C++ way...
    [MAX4466.hpp]
2021-01-20 sync - new display driver, refactor, compiler error squashing...
2021-01-21 create manager and driver objects
2021-02-15 update gitignore for Kicad
2021-02-15 KiCad Schematic for ShotTimer
    [ShotTimer.kicad_pcb, ShotTimer.sch, kibom-test.kicad_pcb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]
2021-02-25 Rev 1.1 - optimized parts, updated BOM, reorged kicad part deps, started PCB layout
    [ShotTimer.kicad_pcb, ShotTimer.sch]
2021-03-06 initial pcb layout, bump to rev 1.2 remove 10uF caps, tidy up
    [ShotTimer.kicad_pcb, ShotTimer.sch]
2021-03-12 PCB REV1.3 - first design sent to fab.
    [ShotTimer-B_Cu.gbr, ShotTimer-B_Mask.gbr, ShotTimer-B_SilkS.gbr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]
2021-03-25 final boms for hw versions
    [ShotTimer_bom_1.0_(udefault).csv, ShotTimer_bom_1.2_(udefault).csv, ShotTimer_bom_1.3_(udefault).csv]
2021-03-25 old fritzing start of a design... saving into git just for funsies
    [Breadboard_Design_v3.fzz]
2021-03-25 basic driver for MC3201 ADC via SPI communication
2021-03-27 move .git up a level to match AS7/VS proj structure
    [Breadboard_Design.fzz, Breadboard_Design_v2.fzz, Breadboard_Design_v3.fzz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]
2021-03-27 move hardware folder to tld
    [Breadboard_Design.fzz, Breadboard_Design_v2.fzz, Breadboard_Design_v3.fzz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]
2021-03-28 standardize include format, fix startup functions
    [ShotTimer.cpp]
2021-04-25 start of the US2066 SPI driver implementation
2021-05-02 fix compiler errors and missing cursor position reset
    [US2066.cpp]
2021-05-02 finished basic US2066 driver, untested on device.

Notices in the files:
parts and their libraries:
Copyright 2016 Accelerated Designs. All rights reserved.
